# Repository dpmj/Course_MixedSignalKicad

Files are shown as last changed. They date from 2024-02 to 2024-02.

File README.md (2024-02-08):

# Mixed-Signal Hardware Design with KiCad

My complete KiCAD project and report.

All my content is licensed under CERN-OHL-S (CERN Open Hardware Licence Version 2 - Strongly Reciprocal). 

Third-party desing elements included in this repository are subject to the copyright of their respective owners.

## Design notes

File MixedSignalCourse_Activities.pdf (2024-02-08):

# Submission of course activities

### Mixed-Signal Hardware Design with KiCad

# Prof. Philip Salmony – FEDEVEL Academy

### Juan Del Pino Mena

dpmj@protonmail.com

Telecommunications Engineer

MEng. Telecommunications & MEng. Electronic Systems student

at Universitat Politècnica de València (Spain)

### February 8, 2024

Mixed-Signal Hardware Design with KiCad | Submission of course activities | 1

# This document is licensed under the CC BY-NC-SA 4.0 (Attribution-NonCommercial-ShareAlike 4.0 International)

The licensor cannot revoke these freedoms as long as you follow the license terms.

- Share – copy and redistribute the material in any medium or format
- Adapt – remix, transform, and build upon the material

Under the following terms:

- Attribution – You must give appropriate credit , provide a link to the license, and in-

dicate if changes were made . You may do so in any reasonable manner, but not in any

way that suggests the licensor endorses you or your use.

- NonCommercial – You may not use the material for commercial purposes.
- ShareAlike – If you remix, transform, or build upon the material, you must distribute

your contributions under the same license as the original.

# https://creativecommons.org/licenses/by-nc-sa/4.0/

Juan Del Pino Mena | 1

Mixed-Signal Hardware Design with KiCad | Submission of course activities | 2

# Contents

Lesson 3 | Part Selection | 3
Lesson 4 | How To Read A Datasheet and Circuit Design Introduction | 7
Lesson 5 | Schematic Design - Power Supply | 8
Lesson 6 | Schematic Design - Microcontroller, USB, SWD, and ESD Protection | 10
Lesson 8 | Final Schematic Tips, Footprint Selection, and Footprint Creation | 11
Lesson 9 | Circuit Simulation with LTSpice | 12
Lesson 11 PCB - Design Rules and Set-Up | 13
Lesson 12 PCB - Layout | 15
Lesson 13 PCB - Routing | 17
Lesson 14 PCB - Finishing touches | 22
Lesson 15 Getting The Product Manufactured | 23
Conclusions | 24
References | | 25

Mixed-Signal Hardware Design with KiCad | Submission of course activities | 3

# Lesson 3 Part Selection

# 3.1 Part Selection For Your Own Design

Try to follow the part selection steps (‘basics’) outlined in this video to perform the part

# selection for your own, previous electronics project. Have your part selections changed from what you previously chose? Did you require additional components?

Last year, for my bachelor’s thesis, I developed a portable device to capture and process

signals from two piezoelectric sensors and display the result on an LCD screen. It was my

first ‘serious’ PCB design. Due to my lack of experience and the limited stock in the lab I was

working in, I chose some components that I would not use now:

- The microcontroller was an Espressif ESP32-WROOM-32D, not the latest, but a very

popular µC in the DIY world, and it had the processing power and wireless capabili-

ties needed for the project. However, it’s not very well maintained and documented

(especially on the software side) and is not recommended for new designs (NRND).

- As the ESP32-WROOM-32D has no USB peripherals, a USB-to-UART converter was

needed. Again, due to various constraints, I ended up using a CH340C, which proved to

be very problematic. The USB port was a mini-USB, which is robust but discontinued.

- To save costs, the idea was to use the two ADC peripherals integrated in the ESP32-

WROOM-32D to acquire from both sensors simultaneously. However, in order to sample

at the required speed (about 200 kSps) it was essential to use DMA, but only one of the

peripherals was capable of using it, so the sampling rate had to be reduced. I also found

the acquisition period to be inconsistent.

- The device was powered by a Li-Po battery, and the charging circuitry was based on a

TP4056. Although simple, it’s a linear charger –so very inefficient– and had no power

path control.

Today, I think an adequate replacement would be the ESP32-S3-WROOM-1 for both the

ESP32-WROOM-32D and CH340C. If I ever needed a USB-to-UART converter, I would choose a

Silicon Labs CP2102N or similar. As for the ADCs, a more reliable alternative is the ADS78XX

series from Texas Instruments. The battery charger could be replaced by a switched mode

charger such as the BQ25629 from TI. And the USB port should be updated to a Type-C.

# 3.2 Distributor Part Search

Go to other electronics distributor websites (DigiKey, Farnell, ...) and try out their part

# search using the example from the video. How do the part searches compare? Which one do you prefer?

They are very similar. For electronic components, I personally prefer Mouser and DigiKey

to shops with a wider product range such as Farnell and RS Components because the search

filters are more precise. However, for specialised products such as microcontrollers, DC/DC

converters, sensors or ADCs, I prefer to select them directly from the manufacturer’s website

(STM, Analog, Microchip, TI...) and then search for stock and prices in online shops.

Mixed-Signal Hardware Design with KiCad | Submission of course activities | 4

# 3.3 Microcontroller Choice

# What microcontroller alternatives would you choose for this design? Are there any pinto-pin compatible microcontrollers that could be used as a replacement?

In Mouser, setting the filter to: Manufacturer = STM, Data bus width = 32 bits, Clock

Frequency = 48 MHz onwards, RAM = at least 20 kB, ROM = greater or equal than 128 kB

and Power supply = from 2.4 to 3.6 V. Leaving the package and number of pins unchosen and

sorting by price, the first microcontroller that appears in stock is the STM32F030CCT6. How-

ever, this µC lacks USB. Looking for similar chips on the manufacturer’s website but with USB

support, reveals the STM32F302C series, which are optimized for mixed-signal applications

and could even replace the ADCs.

A pin-to-pin compatible, drop-in replacement for the STM32F103CBT6 would be any of

the F1 or F3 series [1] with the same LQFP-48 package, like the STM32F302CBT6. The ability

to reconfigure the STM32 pins helps to find alternatives in the same manufacturer. Also, there

are clones of the popular STM32F103, e.g. the AIR32F103.

# 3.4 Data Converters

# What alternative data converters (ADCs and DACs) would you choose that are suitable for this application?

ADC The basic requirements are: single-channel (or more if price is not affected), single-

ended or differential, 12 bits, and at least 40 kSps, with SPI interface and support for 3.3

V. Some ≤ 2 e options gathered from Mouser:

## - Microchip MCP33141D / MCP33151D

## - OnSemi NCD98010 / NCD98011

- Texas Instruments ADS7826 / ADS7827 / ADS7829

DAC The requirements are identical to those of the ADC. Some inexpensive options are listed

below:

## - Analog Devices AD5601 / AD5611 / AD5621

## - Microchip MCP48FVB2X / MCP48CXB2X

- Texas Instruments DAC7512

# 3.5 Power Supplies

# If we use a linear, LDO regulator with a dropout voltage of +1V1 for all +3V3 rails in our design, what power loss would we suffer?

To calculate the dissipated power PD in a LDO, it is necessary to consider the dropout

voltage VDO and the current passing through it I. In our case, VDO = 1.1 V, but the current is

undefined. Assuming I = 0.1 A:

PD = VDO · I = 1.1 V · 0.1 A = 0.11W | (1)

Mixed-Signal Hardware Design with KiCad | Submission of course activities | 5

# 3.6 Analogue Circuitry

Compare the Johnson noise of the three following resistors: 100 Ohms, 1k, and 10k.

# What is the combined Johnson noise of two resistors in parallel, and two resistors in series?

Johnson noise, also known as thermal noise, arises due to the thermal agitation of charge

carriers in a resistive medium. It is characterized by its root mean square (RMS) voltage:

Vrms =

p
4 · kB · T · R · B | (2)
- kB is Boltzmann’s constant (≈ 1.38 × 10⁻²³ J/K).
- T is the temperature in Kelvin.
- R is the resistance in Ohms.
- B is the bandwidth in Hertzs.

Assuming a room temperature of T = 25 ◦C ≡ 298 K and a normalized bandwidth (B = 1 Hz),
the noise RMS voltage is 1.28 nV for 100 Ω, 4.06 nV for 1 kΩ, and 12.83 nV for 10 kΩ.

When combining two resistors, the noise will depend on their total resistance:

# Series RS = R1 + R2, so that Vrms,S =

p
4 · kB · T · (R1 + R2) · B. The sum of two resis-

tances greater than zero will always be greater than either part, and since the noise is

directly dependent on the resistance, it will also be greater.

# Parallel RP = R1||R2 =

R1·R2
R1+R2

, and so, Vrms,P =

q

# 4 · kB · T ·

R1·R2
R1+R2
- B. As we know, the

value resulting from the parallel of two resistors (non-zero and non-infinite) is less than

the value of the resistors themselves, so the noise will be lower.

# 3.7 Surrounding Circuitry

# Look up the differences between various ceramic capacitor types (X5R, Y5V, C0G, and so on). What are each’s benefits and drawbacks?

There are different classes of capacitor dielectrics [2]:

Class 1 Temperature compensating capacitors. They have a predictable temperature coeffi-

cient and do not tend to suffer with aging.

Class 2 General purpose ceramic capacitors. They offer high capacitance values in a small

size, but can be severely affected by temperature, voltage (both AC and DC), frequency

and aging.

In a MLCC capacitor, the first character of the code indicates the lowest temperature

that the capacitor can handle, the second character the maximum temperature, and the third

character the maximum amount of capacitance change over the part’s temperature range. A

qualitative comparison between several common types of capacitors is shown below:

X5R Relatively high capacitance per unit volume and are cost-effective. Suitable for applica-

tions where moderate capacitance are needed. However, X5R capacitors have a signifi-

cant capacitance change with temperature and voltage.

Mixed-Signal Hardware Design with KiCad | Submission of course activities | 6

Y5V High capacitance. Commonly used for decoupling, where their capacitance shift with

temperature and voltage are not critical. Their temperature operation range is reduced.

Z5U Similar to Y5V, but with narrowed operating temperature range.

X7R Good balance between temperature stability and capacitance values. Still not suitable

for high-precision applications.

C0G Also called NP0 (Class 1). Very low capacitance drift over temperature variations and

voltage biases. Low losses and high Q factors, suitable for precision applications. How-

ever, they tend to have lower capacitance values compared to class 2 capacitors. They

can also be more expensive.

Mixed-Signal Hardware Design with KiCad | Submission of course activities | 7

# Lesson 4 How To Read A Datasheet and Circuit Design Introduction

# Open the datasheet for the DAC IC used in this design. Is the datasheet arranged in a similar way? What are the key sections?

The datasheet of the DACxx6x series [3] is organised identically to the TLV62569 DC/DC

converter one. This is partly because all IC datasheets follow a similar structure, and mainly

because they are from the same manufacturer, Texas Instruments, which has very standardised

documents. The key sections are:

1. Features
2. Applications
3. Description
4. Revision history
5. Device comparison table
6. Pin configuration and functions
7. Specifications
8. Detailed description
9. Application and implementation
10. Power supply recommendations
11. Layout
12. Device and documentation support
13. Mechanical, packaging and orderable information

Mixed-Signal Hardware Design with KiCad | Submission of course activities | 8

# Lesson 5 Schematic Design - Power Supply

# 5.1 RLC Filters

# Using the online RLC filter tool, design an RLC low-pass filter that has a cut-off frequency of 100 kHz and damping ratio of 1.25. Inspect the frequency response, and note the inductor and resistor values. What capacitor size did you choose?

The data from avobe is entered in the RLC Low-pass Filter Design Tool hosted in Okawa

Electric Design website [4]: cutoff frequency 100 kHz and damping ratio 1.25. The capacitor

value is chosen as C = 100 nH. Forcing the value of the coil and the resistor to be from

commercial series, R = 39 Ω and L = 22 uH are obtained, which are adequate values. The

frequency response obtained is shown in Figure 1. Due to the constraint to stick to commercial

values, the cut-off frequency has slightly shifted to 107.3 kHz.

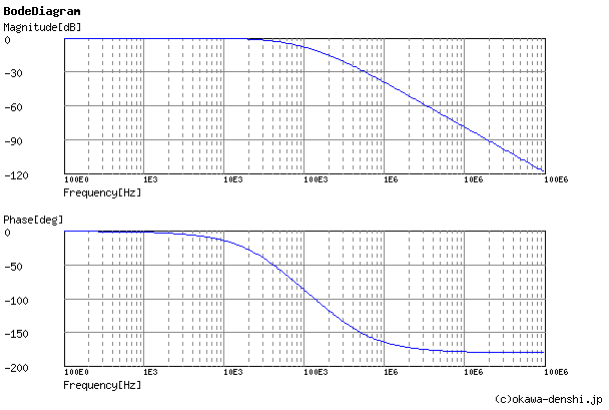
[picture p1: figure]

Figure 1 – Frequency response of the 100 kHz RLC filter designed in Okawa Electric Design website
[4].

# 5.2 RC Filters

# Cascade a high-pass RC filter with a low-pass RC filter, and set R=1k for both and C=1nF for both. What type of filter is the combined structure? What is the input impedance vs frequency?

Instead of using the online tool, it has been decided to use LTSpice in order to have more

control over the information obtained from the circuit.

The filter resulting from the cascade of the two proposed high-pass and low-pass filters

is a band-pass (see Figure 3). Due to the overlap of their cut-off frequencies, the passband

attenuates the signal considerably (6 dB). The figure also depicts the input impedance as a

function of frequency, which corresponds almost to that of the first stage: the high pass.

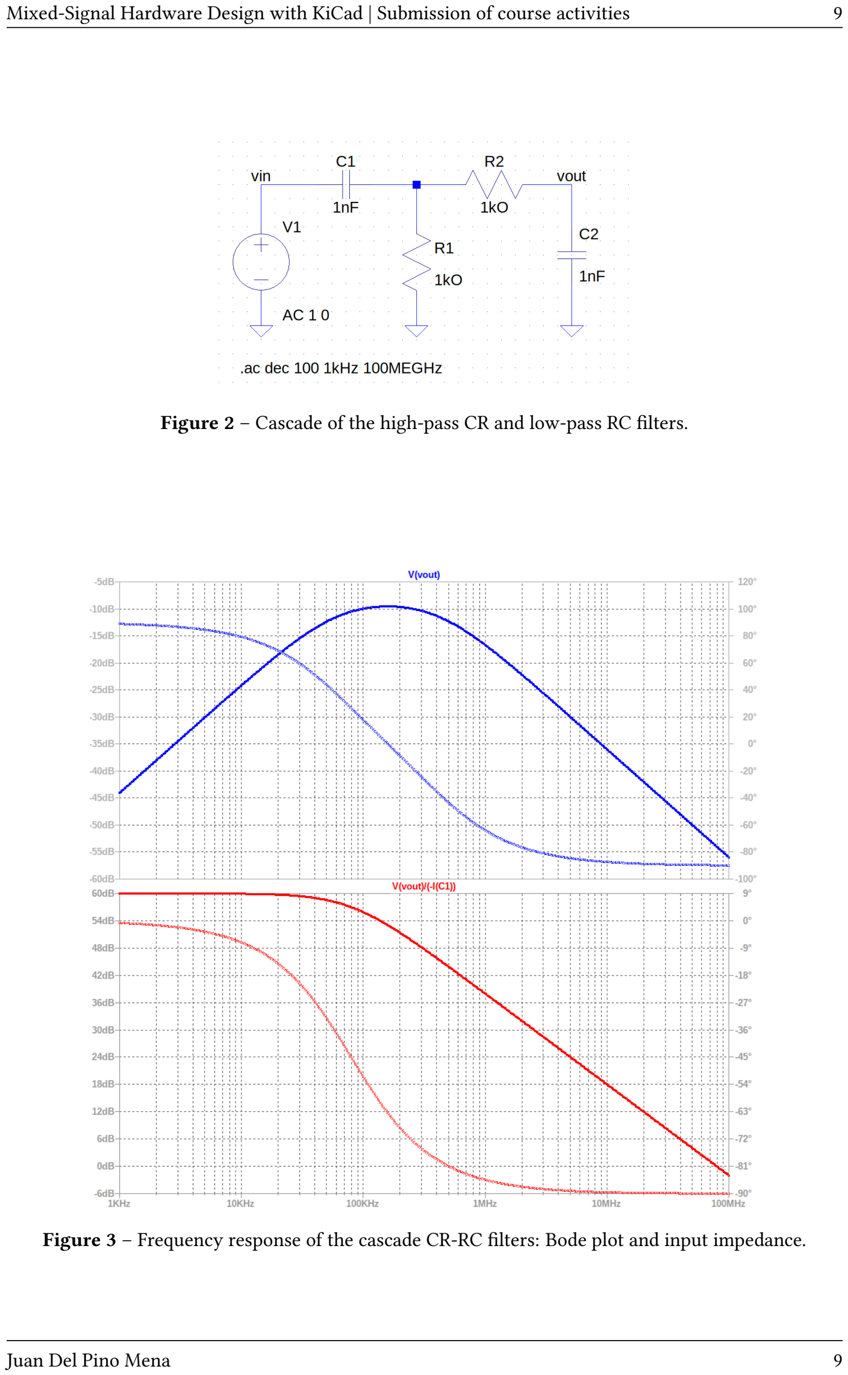
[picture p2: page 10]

Mixed-Signal Hardware Design with KiCad | Submission of course activities | 9

Figure 2 – Cascade of the high-pass CR and low-pass RC filters.

Figure 3 – Frequency response of the cascade CR-RC filters: Bode plot and input impedance.

Mixed-Signal Hardware Design with KiCad | Submission of course activities | 10

Lesson 6 Schematic Design - Microcontroller, USB, SWD,

# and ESD Protection

# Try to select a different STM32 microcontroller, download STM32CubeIDE, and do a

rough pin-out planning given the constraints of this project.

In subsection 3.3 we already discussed the STM32F302CBT6 as a suitable replacement for

the STM32F103CBT6, since it comes in the same LQFP-48 package and has similar characteris-

tics. After installing the STM32CubeIDE and creating a new project based on the STM32F302CBT6

microcontroller, the pin allocation takes place. See Figure 4 for the result, which is pin-to-pin

compatible with the pinout assignment performed in lesson 6.

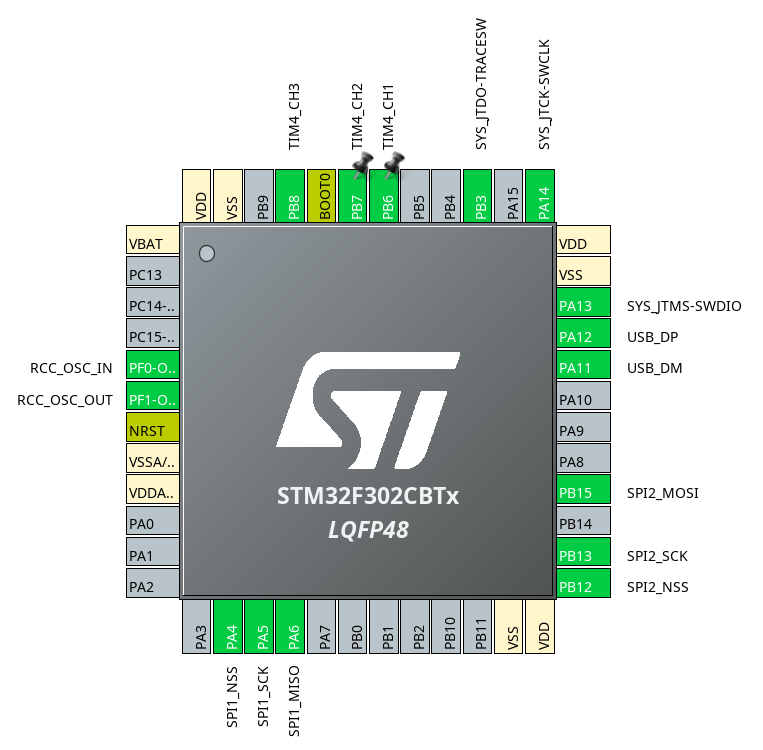
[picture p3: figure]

Figure 4 – STM32F302CBT6 rough pin planning.

Mixed-Signal Hardware Design with KiCad | Submission of course activities | 11

# Lesson 8 Final Schematic Tips, Footprint Selection, and Footprint Creation

# Have a go at trying to make your own footprint for a different part (e.g. the buck con-

verter IC) in KiCad using the datasheet as a guide.

Using the dimensions for the SOT-23-6 package in the TLV62569 DC/DC converter datasheet

[5], KiCad’s footprint wizard for SOIC packages, and the 3D model from Kirk Jess on 3DCon-

tentCentral [6], the footprint of the component has been synthesised, as shown in Figure 5.

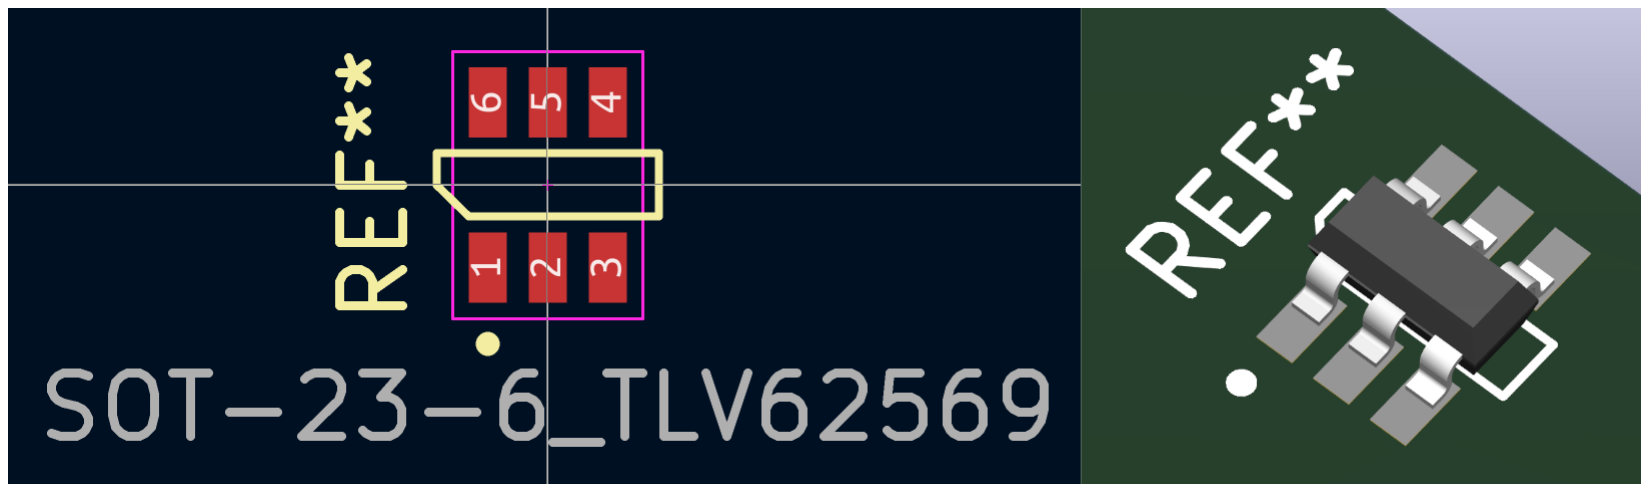
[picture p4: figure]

Figure 5 – 2D and 3D view of the TLV62569 footprint.

Mixed-Signal Hardware Design with KiCad | Submission of course activities | 12

# Lesson 9 Circuit Simulation with LTSpice

# Download and install LTSpice, then try and perform a frequency response analysis of

the 3rd order Butterworth anti-aliasing filter.

The simulated circuit comprises from the decoupling capacitor / high-pass filter at the

input of the follower, up to the balanced output (Figure 6). The resulting frequency response

is plotted in Figure 7. We can first observe the cutoff frequency of the high pass filter (which

differs from the schematic, since it is 0.723 Hz and not 1.4 Hz). The passband extends up to its

cut-off frequency of approximately 24 kHz. At 20 kHz there is an attenuation of about 1 dB.

This filter is suitable for audio applications.

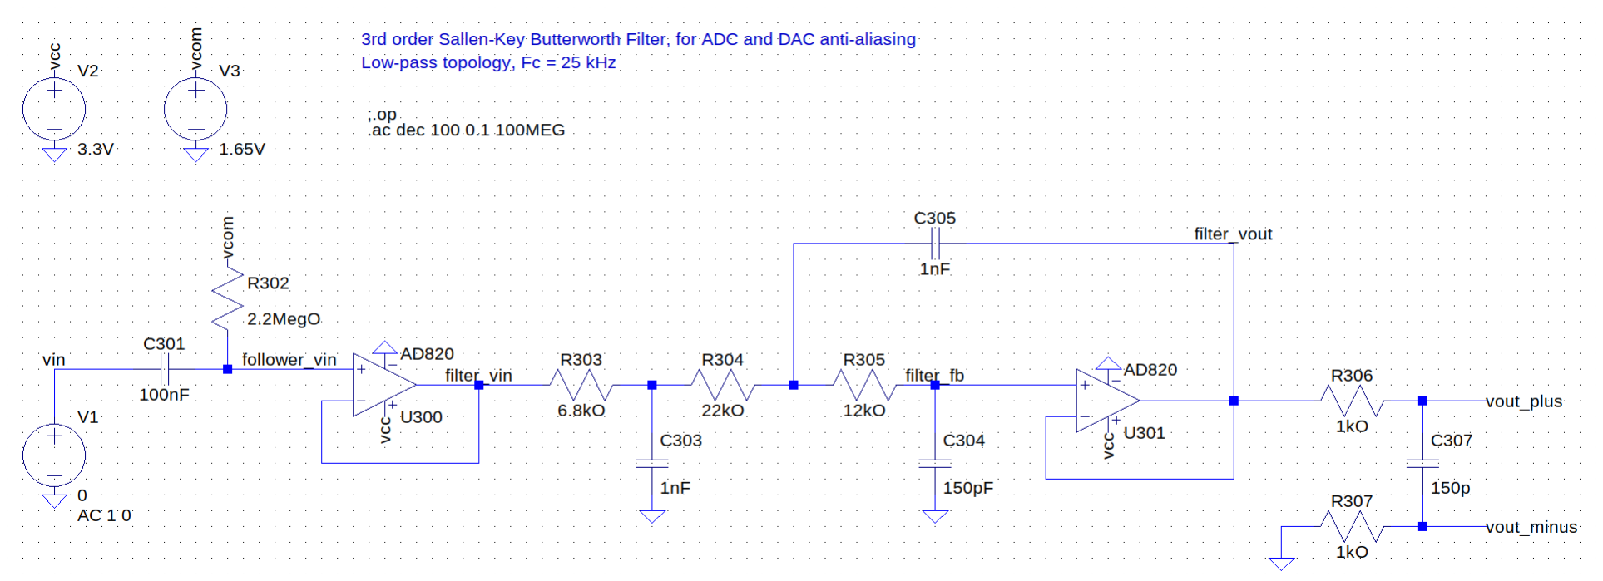
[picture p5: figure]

Figure 6 – Sallen-Key third-order butterworth filter circuit in LTSpice.

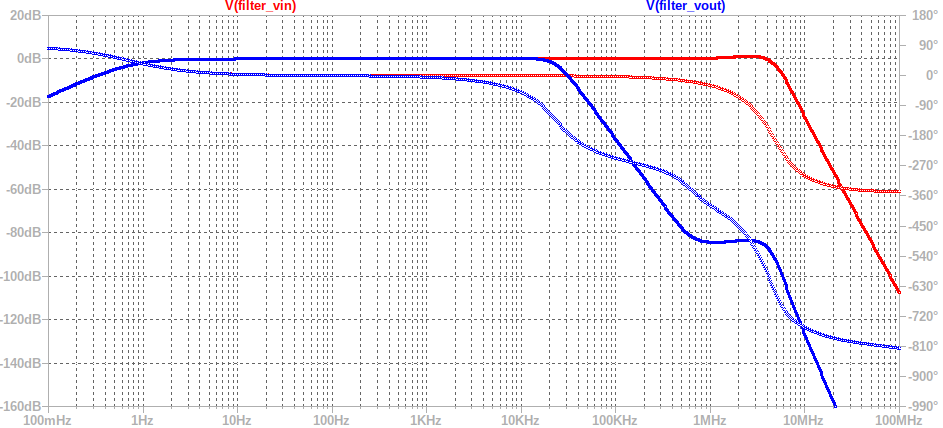
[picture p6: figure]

Figure 7 – Sallen-Key third-order butterworth filter frequency response in LTSpice.

Mixed-Signal Hardware Design with KiCad | Submission of course activities | 13

# Lesson 11 PCB - Design Rules and Set-Up

# Using your own preferred PCB manufacturer’s website, try and fill in all of the required

design rules, as shown in the video, in KiCad.

I have decided to use EuroCircuits as the PCB manufacturer, being one that I have not

used previously. Based on their documentation [7], [8], the 4-layer stackup from the Defined

Impedance Pool has been chosen, and a pattern class 6 and drill class C PCB has been selected.

The stackup and design rules have been specified in the KiCAD configuration as shown in the

screenshots in Figure 8 and Figure 9. The board finish is ENIG. With the chosen stackup, a

90 Ω differential pair at the USB high-speed frequency has the dimensions shown in Figure 10.

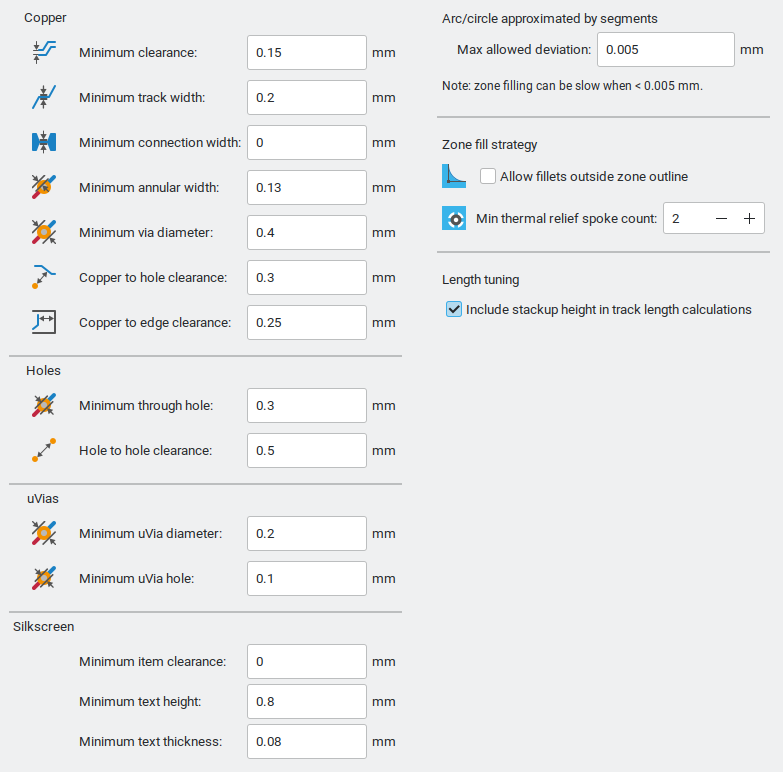
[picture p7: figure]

Figure 8 – KiCAD board setup - Constraints

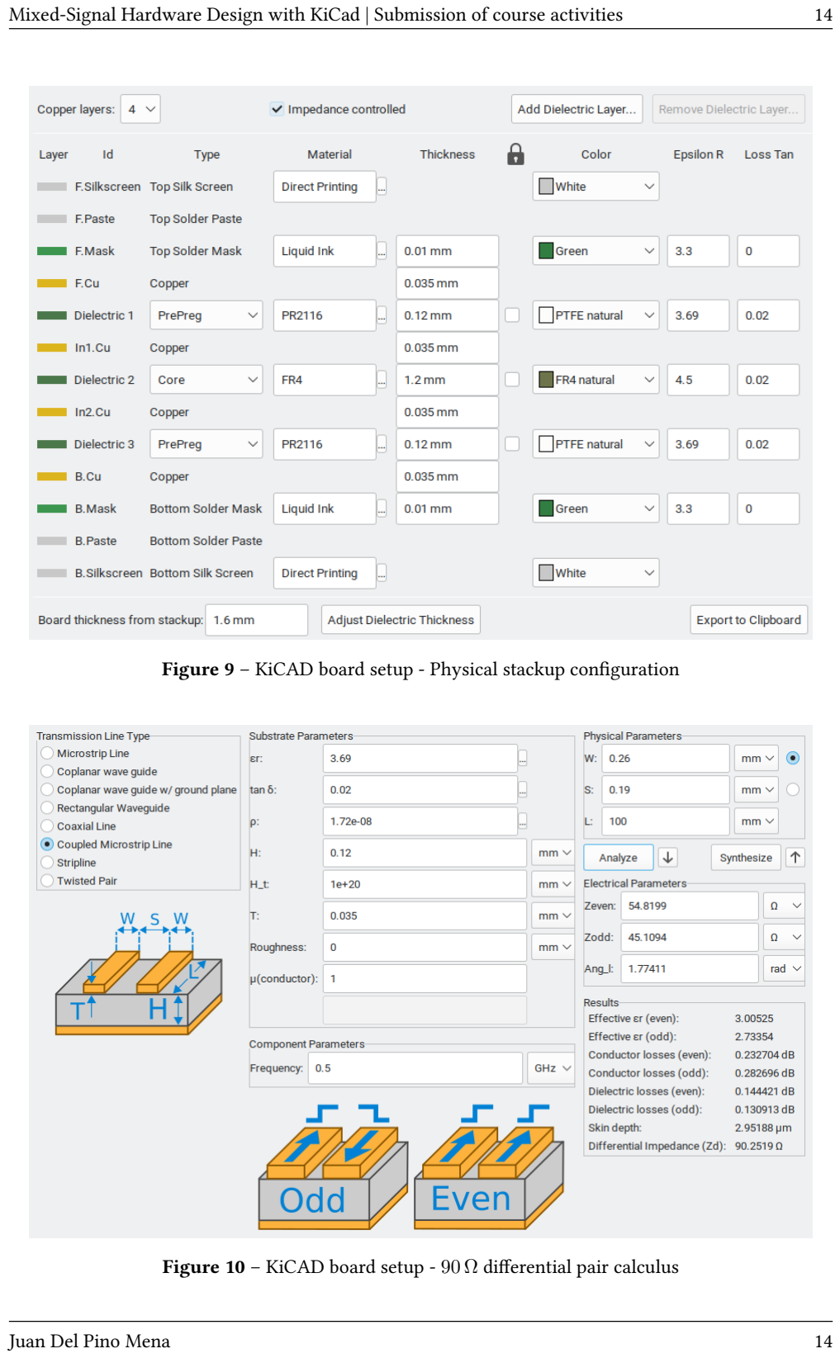
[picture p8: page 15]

Mixed-Signal Hardware Design with KiCad | Submission of course activities | 14

Figure 9 – KiCAD board setup - Physical stackup configuration

Figure 10 – KiCAD board setup - 90 Ω differential pair calculus

Mixed-Signal Hardware Design with KiCad | Submission of course activities | 15

# Lesson 12 PCB - Layout

# I would strongly encourage you to start from the finished schematic (project files in-

cluded in ’Lesson 1’), and follow along with the layout process - or even try to improve on the layout shown in the video. This step is needed to be eligible for a course certificate.

The missing 3D models from the BNC connectors, USB Type-C, ADC, DAC, buck con-

verter inductor, and common-mode choke have been added. Some have been obtained from

the built-in KiCAD library at $KICAD7_3DMODEL_DIR/ whereas others are in

# $KIPRJMOD/Juan_Footprints_Lib/3D/

Rather than following the video step by step and doing it exactly the same, I have decided

to follow the recommendations but varying the layout by constraining the design to a PCB

that fits a Hammond Manufacturing 1457C802EBK enclosure [9]. Clearance zones have been

defined to prevent components from colliding with the housing and its rails.

The early layout is shown in Figure 11. A 3D view of the board is shown in Figure 12.

The layout is divided into zones according to the schematic sheets, with enough space between

them for easy routing.

Note: As the 1457C802EBK case is EMC/EMI shielded, an extra earth net has been

added to the design to connect the mounting holes and the shield of the USB connector. Un-

fortunately, the BNC connectors can’t benefit from this earth, as the metal structure is directly

connected to GND.

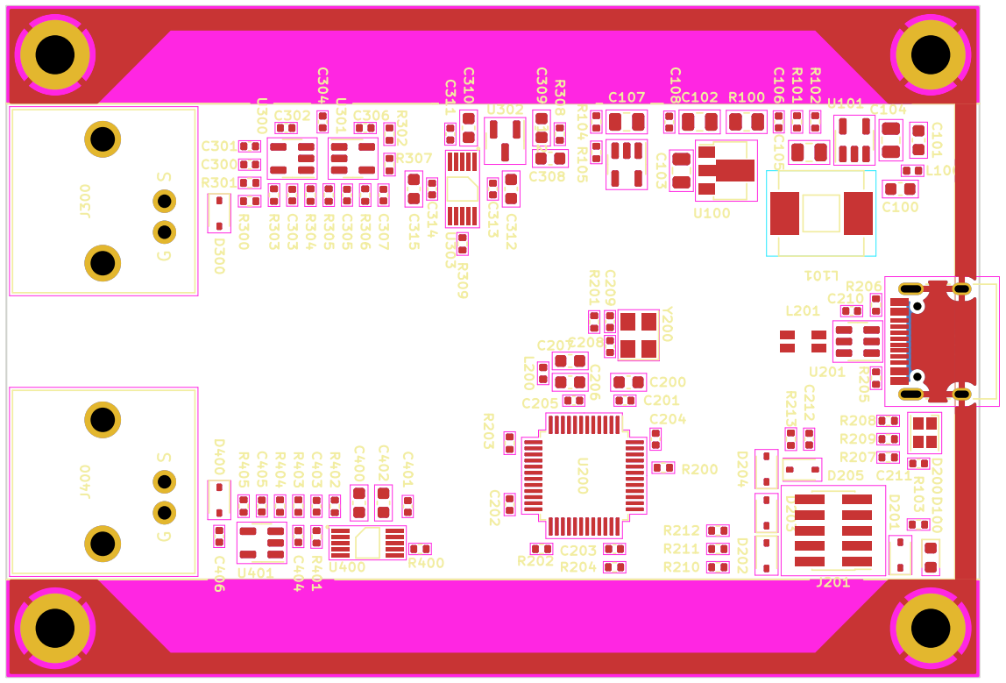
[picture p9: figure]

Figure 11 – Preliminary layout of the board – 2D view

Mixed-Signal Hardware Design with KiCad | Submission of course activities | 16

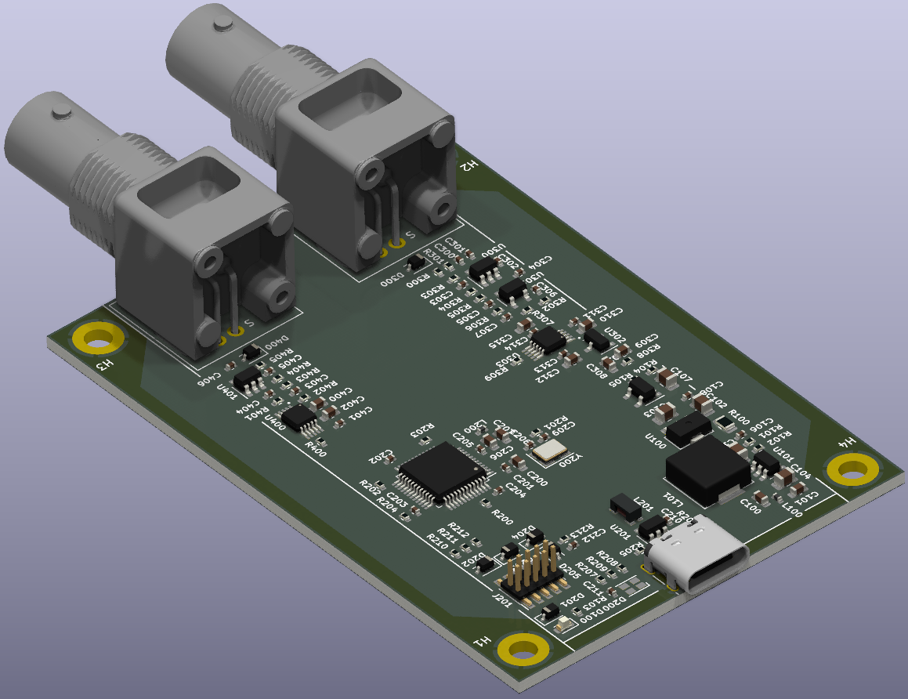
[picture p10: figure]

Figure 12 – Preliminary layout of the board – 3D view

Mixed-Signal Hardware Design with KiCad | Submission of course activities | 17

# Lesson 13 PCB - Routing

# You should now try to route out the complete PCB by yourself, following the guidelines

in this video. This step is needed to be eligible for a course certificate.

The layout of the board has undergone minimal change from previous lesson. The top

layer accommodates the majority of signal traces and routing, while the bottom layer provides

additional signal bridges and power distribution. Polygon pours are widely used, to optimise

for lower voltage drops –even for lower current circuits– given that there is plenty of space.

To ensure signal integrity, return path vias are placed for all signals undergoing layer

changes. In addition, via stitching is performed on both the ground and earth planes. Earth

features exposed copper to make a connection to the metal housing.

The board has no Design Rule Check errors. Some footprints had to be updated to solve

warnings. Only a handful of non-critical warnings remain, due to the silkscreen of the USB

being cropped by the board outline.

In Figure 13 an updated 3D view of the board is shown. On the following pages are

several prints of the board layers.

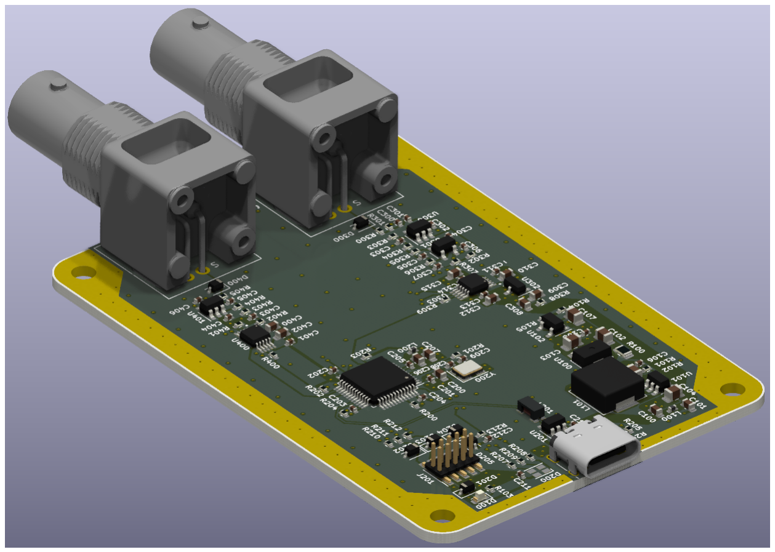
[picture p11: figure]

Figure 13 – 3D view of the board, finished layout and routing

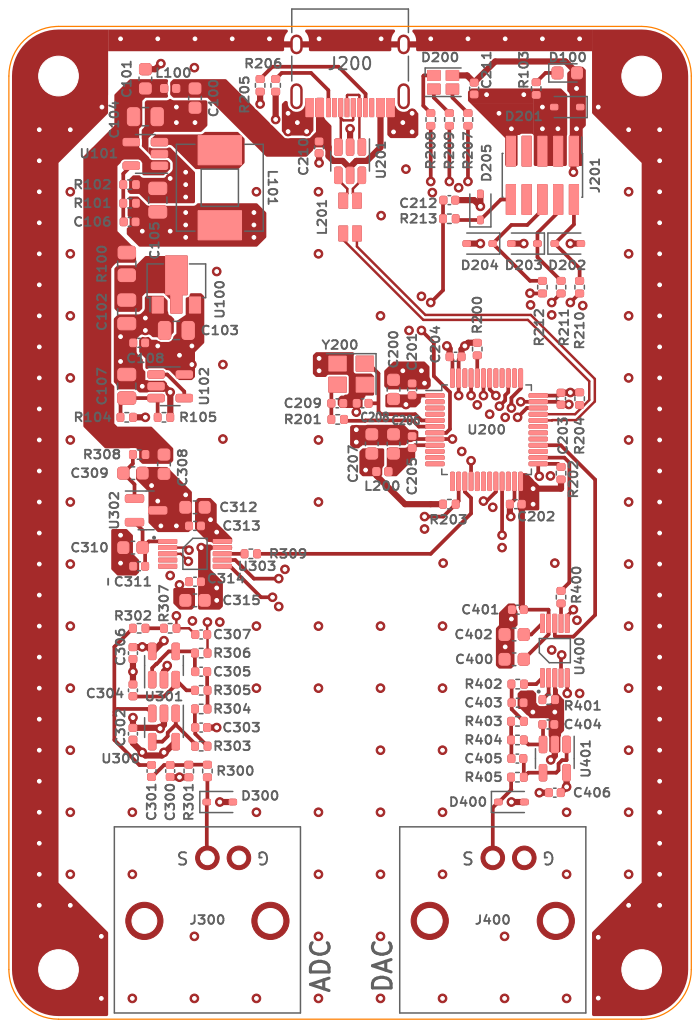
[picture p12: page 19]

File: Nemesis-MixSigPCB.kicad_pcb Sheet: Juan Del Pino Mena

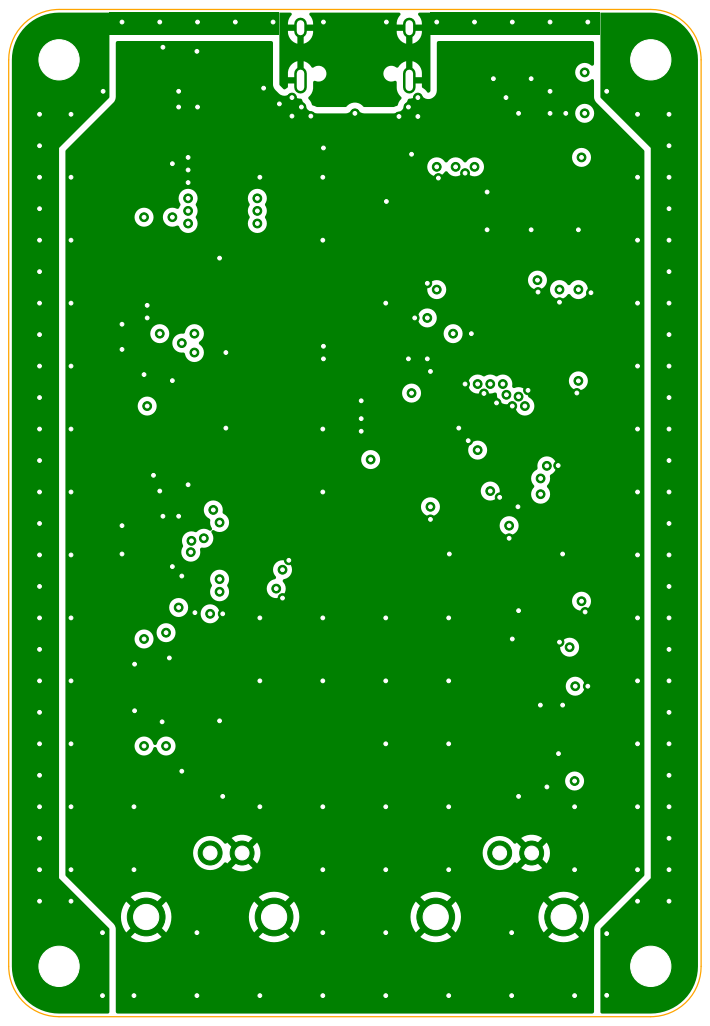
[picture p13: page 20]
D Date: 2023-09-22 KiCad; kicad; 7.0.10 Size: A4; Rev: 1; Id: 1/1 Title: Mixed-Signal; Hardware Design with KiCad - PCB; File: Nemesis-MixSigPCB.kicad_pcb Sheet: Juan; Del; Pino; Mena

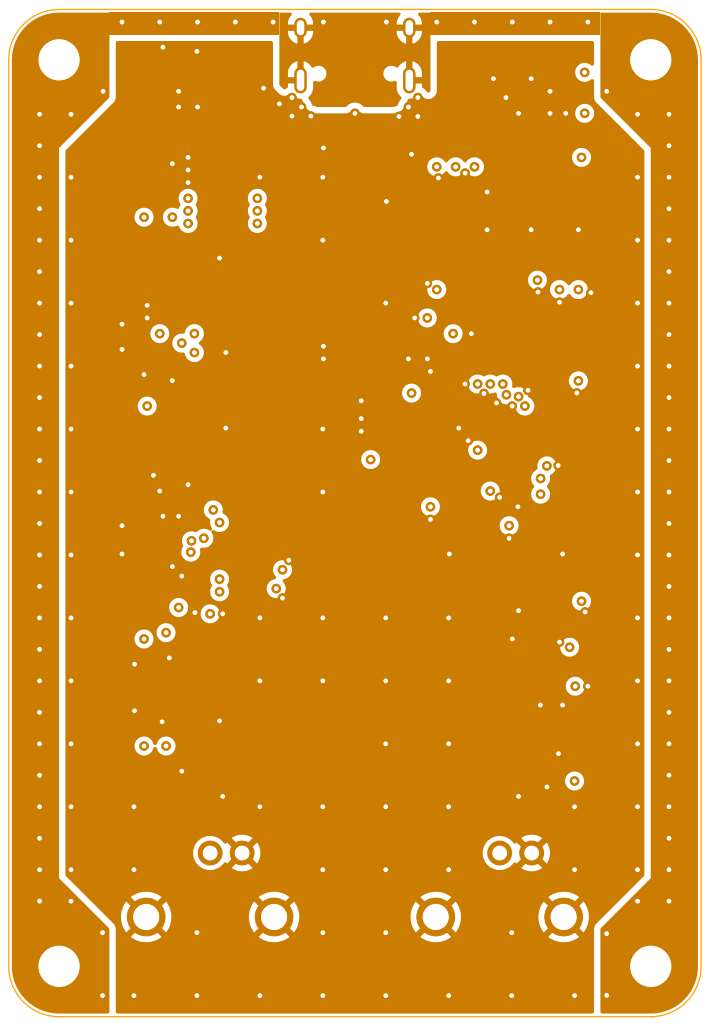
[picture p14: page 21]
D Date: 2023-09-22 KiCad; kicad; 7.0.10 Size: A4; Rev: 1; Id: 1/1 Title: Mixed-Signal; Hardware Design with KiCad - PCB; File: Nemesis-MixSigPCB.kicad_pcb Sheet: Juan; Del; Pino; Mena

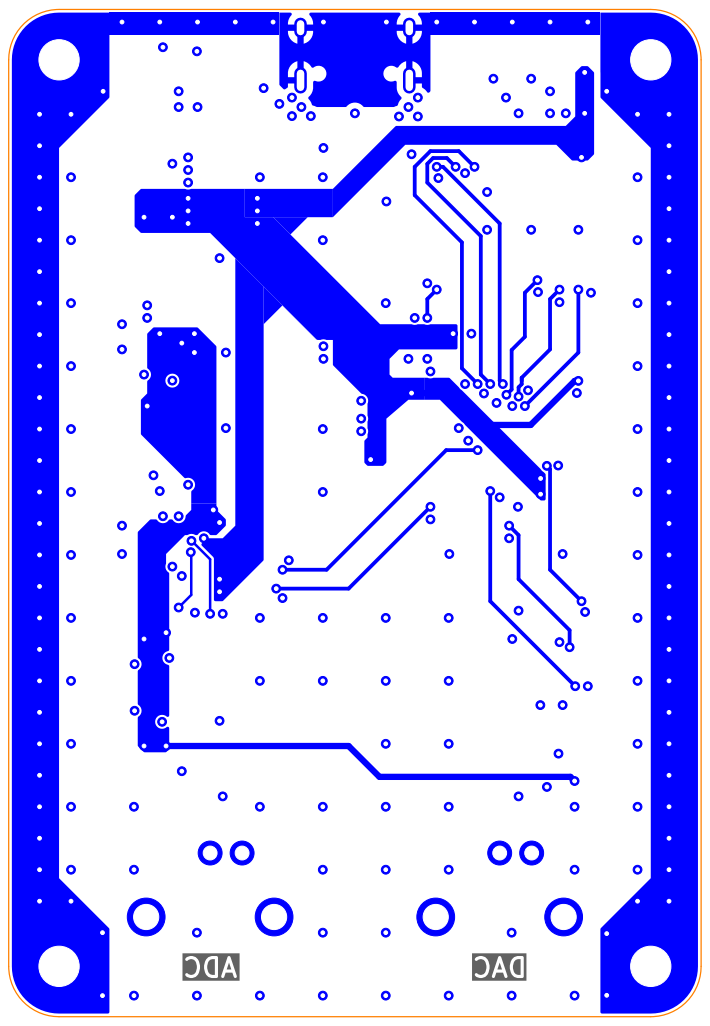
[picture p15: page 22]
D Date: 2023-09-22 KiCad; kicad; 7.0.10 Size: A4; Rev: 1; Id: 1/1 Title: Mixed-Signal; Hardware Design with KiCad - PCB; File: Nemesis-MixSigPCB.kicad_pcb Sheet: Juan; Del; Pino; Mena

Mixed-Signal Hardware Design with KiCad | Submission of course activities | 22

# Lesson 14 PCB - Finishing touches

# Try to add your own logo and silkscreen to your PCB design. How would you go about adding tooling holes for assembly?

Some decorative silkscreen has been added in the bottom layer.

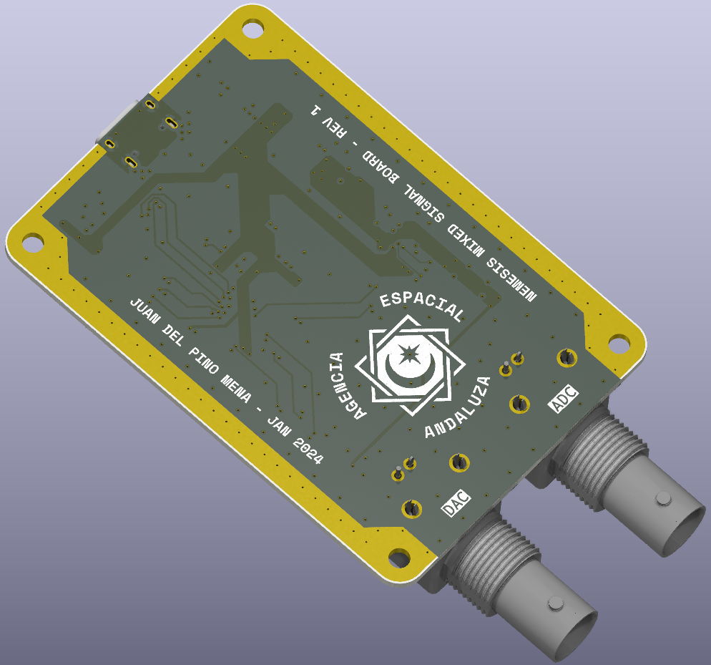
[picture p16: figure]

Figure 14 – 3D view of the board, bottom view.

Mixed-Signal Hardware Design with KiCad | Submission of course activities | 23

# Lesson 15 Getting The Product Manufactured

# Try to export Gerber and Drill files, as well as assembly files (footprint position and

BOM) for yourself in KiCad.

A manufacturer and part number has been provided for every component in the design.

Gerber and Drill files are exported to the Gerber/ folder inside the project. Gerber files have

been checked. Assembly files (placement and bill of materials) are placed in the Assembly/

folder.

JLCPCB automatically detects all features of the board when the gerbers are uploaded.

Selected specs are: 4 layers, controlled impedance (stackup JLC0416H-7628), green solder

mask, white silkscreen, FR-4 TG 155ºC, ENIG surface finish, 1 oz/ft² in external layers, 0.5

oz/ft² in internal layers, plugged vias, 0.3 mm minimum via hole, 0.2 mm tolerance in board

cutout, and assembly of 5 boards. The price is $ 37.39.

In Eurocircuits both the gerbers and the assembly files are correctly identified. For the

controlled impedance pool (which is the one actually this project is designed for), and selecting

similar specs to those selected in JLCPCB, the total price is e 220.70.

Mixed-Signal Hardware Design with KiCad | Submission of course activities | 24

# Conclusions

I found this course quite complete. The explanations were clear, sufficient and practical, high-

lighting the key aspects needed to develop intuition when designing boards. I already had

some experience, but I found all the details explained in the schematics, topology and compo-

nent selection very helpful.

Giving the students basic materials is a double-edged sword: on the one hand, it gives ev-

eryone a common starting point, abstracts some of the design process and speeds up progress

towards completion. But on the other hand, we lose part of the experience. I think I would

have done an extra lesson on how to create a new schematic sheet from scratch. It would also

have been nice to take advantage of the extensive and high quality symbol, footprint and 3D

libraries that come with KiCAD.

I found some problems with the resources provided, such as outdated PCB footprints

and schematic symbols, which were annoying. But on the positive side, these problems made

me look for solutions on my own, and I became more confident with KiCAD.

Also, this was my first project in KiCAD and I found it very fast, convenient and exten-

sible. In some ways I think it puts bloated software like Altium Designer to shame. Thank you

for introducing me to this wonderful piece of open source software!

Mixed-Signal Hardware Design with KiCad | Submission of course activities | 25

# References

[1] ST Microelectronics Inc., Migrating from STM32F1 Series to STM32F3 Series microcontrollers, Appli-

cation Note AN4228. DocID024110, Rev 6, Feb 2017. Available online: https://www.st.com/

# resource / en / application _ note / dm00024853 - migration - and - compatibility -

guidelines- for- stm32- microcontroller- applications- stmicroelectronics. pdf. (https://www.st.com/resource/en/application_note/dm00024853-migration-and-compatibility-guidelines-for-stm32-microcontroller-applications-stmicroelectronics.pdf)

[2] C. Kaiser, The Capacitor Handbook. Springer Netherlands, 2012, isbn: 9789401180900.
[3] T. I. Inc., DACxx6x series datasheet, Document number SLAS719E, August 2010, Revised June 2015.
Available online: https://www.ti.com/lit/gpn/DAC7563.
[4] O. E. Design, Engineering design utilities, Available online: http://sim.okawa-denshi.jp/

# en/. (http://sim.okawa-denshi.jp/en/)

[5] T. I. Inc., TLV62569 datasheet, Document number SLVSDG1C. December 2016, Revised October
2017. Available online: https://www.ti.com/lit/gpn/tlv62569.
[6] K. Jess, SOT-23-6 3D model, Available online: https://www.3dcontentcentral.es/downloadmodel.aspx?catalogid=171&id=93222. (https://www.3dcontentcentral.es/download-model.aspx?catalogid=171&id=93222)
[7] Eurocircuits, PCB configurator: Services, pool, technology, buildup, Available online: https://be.eurocircuits.com/shop/assembly/configurator.aspx. (https://be.eurocircuits.com/shop/assembly/configurator.aspx)
[8] Eurocircuits, PCB design guidelines: Classification, Available online: https://www.eurocircuits.com/pcb-design-guidelines/classification/. (https://www.eurocircuits.com/pcb-design-guidelines/classification/)
[9] Hammond Manufacturing Ltd., EMI/RFI shielded extruded aluminum enclosure, pn 1457c802ebk datasheet, Available online: https://www.hammfg.com/files/parts/pdf/1457C802EBK.

# pdf. (https://www.hammfg.com/files/parts/pdf/1457C802EBK.pdf)

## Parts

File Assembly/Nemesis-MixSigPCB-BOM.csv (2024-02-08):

Source: | /home/boi/Syncthing/Courses/2023-08 PhilsLab KiCad MixedSignal/MixSigCouse-KiCad-Files/Nemesis-MixSigPCB.kicad_sch
Date: | Sun 21 Jan 2024 09:14:26 PM CET
Tool: | Eeschema 7.0.10
Generator: | /usr/share/kicad/plugins/bom_csv_grouped_by_value_with_fp.py
Component Count: | 114
Ref | Qnty | Value | Cmp name | Footprint | Description | Vendor | DNP | Manufacturer | Manufacturer Part Number
C100, C101, C206, C207, C402 | 5 | 1u | C | Capacitor_SMD:C_0603_1608Metric | Unpolarized capacitor |  | KEMET | C0603C105K8RACAUTO7411
C102, C103, C104, C105, C107 | 5 | 22u | C | Capacitor_SMD:C_0805_2012Metric | Unpolarized capacitor |  | Samsung Electro-Mechanics | CL21A226KPCLRNC
C106 | 1 | DNP | C | Capacitor_SMD:C_0402_1005Metric | Unpolarized capacitor
C108, C201, C202, C203, C204, C210, C211, C212, C301, C302, C306, C311, C313, C314, C401, C406 | 16 | 100n | C | Capacitor_SMD:C_0402_1005Metric | Unpolarized capacitor |  | KEMET | C0402C104K8RACAUTO
C200, C308, C309, C310, C312, C315, C400 | 7 | 10u | C | Capacitor_SMD:C_0603_1608Metric | Unpolarized capacitor |  | Samsung Electro-Mechanics | CL10A106KQ8NNNL
C205 | 1 | 10n | C | Capacitor_SMD:C_0402_1005Metric | Unpolarized capacitor |  | KEMET | C0402C103K4RACAUTO
C208, C209 | 2 | 10p | C | Capacitor_SMD:C_0402_1005Metric | Unpolarized capacitor |  | Murata Electronics | GRT1555C1H100FA02D
C300, C304, C307, C404 | 4 | 150p | C | Capacitor_SMD:C_0402_1005Metric | Unpolarized capacitor |  | Walsin | 0402N151F100CT
C303, C305, C403, C405 | 4 | 1n | C | Capacitor_SMD:C_0402_1005Metric | Unpolarized capacitor |  | YAGEO | AC0402JRNPO9BN102
D100 | 1 | GREEN | LED | LED_SMD:LED_0603_1608Metric | Light emitting diode
D200 | 1 | LED_RGB_E6C1206RGBC3UDA | LED_RGB_E6C1206RGBC3UDA | LED_SMD:LED_Cree-PLCC4_2x2mm_CW |  |  | EKINGLUX | E6C1206RGBC3UDA
D201, D202, D203, D204, D205, D300, D400 | 7 | PESD3V3L1BA,115 | D_TVS | Diode_SMD:D_SOD-323 | Bidirectional transient-voltage-suppression diode |  | Nexperia | PESD3V3L1BA,115
H1, H2, H3, H4 | 4 | MountingHole_Pad | MountingHole_Pad | MountingHole:MountingHole_3.2mm_M3_ISO7380_Pad | Mounting Hole with connection
J200 | 1 | USB_C_Receptacle_USB2.0 | USB_C_Receptacle_USB2.0 | Juan_Footprints_Lib:USB_C_Receptacle_HRO_TYPE-C-31-M-12 | USB 2.0-only Type-C Receptacle connector |  | Korean Hroparts Elec | TYPE-C-31-M-12
J201 | 1 | 2x5 1.27mm | Conn_02x05_Odd_Even | Connector_PinHeader_1.27mm:PinHeader_2x05_P1.27mm_Vertical_SMD | Generic connector, double row, 02x05, odd/even pin numbering scheme (row 1 odd numbers, row 2 even numbers), script generated (kicad-library-utils/schlib/autogen/connector/) |  | Harwin | M50-3600542R
J300, J400 | 2 | 031-5640-1010 | Conn_Coaxial | PhilsLab_Footprints_KiCad6:AMPHENOL-BNC-031-5640-1010 | coaxial connector (BNC, SMA, SMB, SMC, Cinch/RCA, LEMO, ...) |  | Amphenol RF | 031-5640
L100, L200 | 2 | 10n | L | Inductor_SMD:L_0402_1005Metric | Inductor |  | ABRACON | AISC-0402HP-10NJ-T
L101 | 1 | 15u | L | PhilsLab_Footprints_KiCad6:MWSA0603S | Inductor |  | Shenzhen Sunlord Electronics | MWSA0603S-150MT
L201 | 1 | CMF3216F-900-2P-T | EMI_Filter_LL_1423 | PhilsLab_Footprints_KiCad6:CMC-1206 |  |  | HYHONGYEX | CMF3216F-900-2P-T
R100 | 1 | 10R | R | Resistor_SMD:R_0805_2012Metric | Resistor |  | Bourns | CHP0805AJW-100ELF
R101 | 1 | 100k | R | Resistor_SMD:R_0402_1005Metric | Resistor |  | Panasonic | ERJ-U02J104X
R102, R304, R403 | 3 | 22k | R | Resistor_SMD:R_0402_1005Metric | Resistor |  | Bourns | CR0402-JW-223GLF
R103, R104, R105, R207, R208, R209, R300, R306, R307 | 9 | 1k | R | Resistor_SMD:R_0402_1005Metric | Resistor |  | Bourns | CR0402-JW-102GLF
R200, R202, R203, R401 | 4 | 10k | R | Resistor_SMD:R_0402_1005Metric | Resistor |  | Panasonic | ERJ-PA2J103X
R201, R309, R400 | 3 | 0R | R | Resistor_SMD:R_0402_1005Metric | Resistor |  | Bourns | CR0402AJ/-000GAS
R204 | 1 | 1k5 | R | Resistor_SMD:R_0402_1005Metric | Resistor |  | Panasonic | ERJ-PA2J152X
R205, R206 | 2 | 5k1 | R | Resistor_SMD:R_0402_1005Metric | Resistor |  | Bourns | CR0402-JW-512GLF
R210, R211, R212, R213, R308, R405 | 6 | 49R9 | R | Resistor_SMD:R_0402_1005Metric | Resistor |  | Panasonic | ERJ2RKD49R9X
R301, R302 | 2 | 2M2 | R | Resistor_SMD:R_0402_1005Metric | Resistor |  | Panasonic | ERJ-U02J205X
R303, R402 | 2 | 6k8 | R | Resistor_SMD:R_0402_1005Metric | Resistor |  | Panasonic | ERJ-2GEJ682X
R305, R404 | 2 | 12k | R | Resistor_SMD:R_0402_1005Metric | Resistor |  | Bourns | CR0402-JW-123GLF
U100 | 1 | HT7533-1 | HT75xx-1-SOT89 | Package_TO_SOT_SMD:SOT-89-3 | 100mA Low Dropout Voltage Regulator, Fixed Output, SOT89 |  | Holtek | HT7533-1-SOT89
U101 | 1 | TLV62569DBV | TLV62569DBV | Package_TO_SOT_SMD:SOT-23-5 | High Efficiency Synchronous Buck Converter, Adjustable Output 0.6V-5.5V, 2A, SOT-23-5 |  | Texas Instruments | TLV62569DBVT
U102, U300, U301, U401 | 4 | MCP6001T-E/OT | MCP6001-OT | Package_TO_SOT_SMD:SOT-23-5 | 1MHz, Low-Power Op Amp, SOT-23-5 |  | Microchip Technology | MCP6001T-E/OT
U200 | 1 | STM32F103CBT6 | STM32F103CBTx | Package_QFP:LQFP-48_7x7mm_P0.5mm | ARM Cortex-M3 MCU, 128KB flash, 20KB RAM, 72MHz, 2-3.6V, 37 GPIO, LQFP-48 |  | STMicroelectronics | STM32F103CBT6
U201 | 1 | USBLC6-2SC6 | USBLC6-2SC6 | Package_TO_SOT_SMD:SOT-23-6 | Very low capacitance ESD protection diode, 2 data-line, SOT-23-6 |  | STMicroelectronics | USBLC6-2SC6
U302 | 1 | REF3033AIDBZT | REF3033 | Package_TO_SOT_SMD:SOT-23 | 3.3V 50-ppm/°C Max, 50-μA, CMOS Voltage Reference, SOT-23-3 |  | Texas Instruments | REF3033AIDBZT
U303 | 1 | ADC141S626CIMM_NOPB | ADC141S626CIMM_NOPB | PhilsLab_Footprints_KiCad6:VSSOP-10 |  |  | Texas Instruments | ADC141S626CIMM/NOPB
U400 | 1 | DAC7563SDGSR | DAC7563SDGSR | PhilsLab_Footprints_KiCad6:VSSOP-10 |  |  | Texas Instruments | DAC7563SDGSR
Y200 | 1 | 16MHz | Crystal_GND24 | Crystal:Crystal_SMD_3225-4Pin_3.2x2.5mm | Four pin crystal, GND on pins 2 and 4 |  | ECS | ECS-TXO-3225MV-160-TR

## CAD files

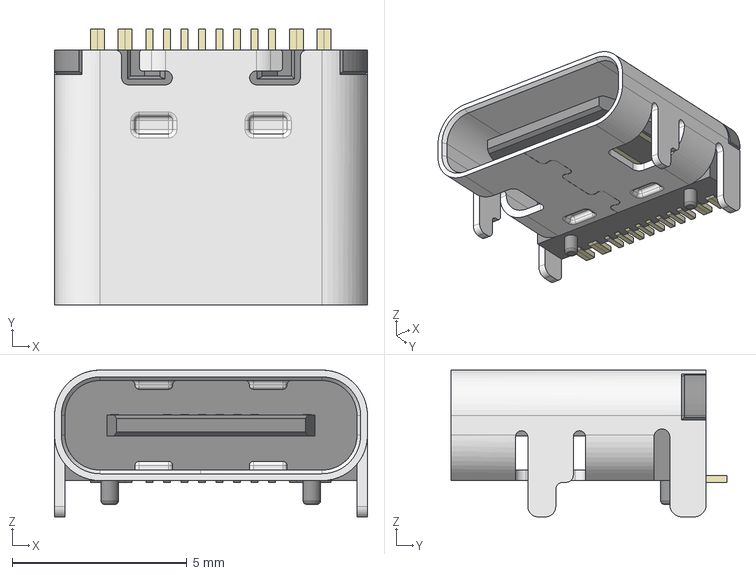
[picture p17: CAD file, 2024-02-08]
Juan_Footprints_Lib/3D/HRO_TYPE-C-31-M-12.step
8.95 x 7.90 x 4.20 mm

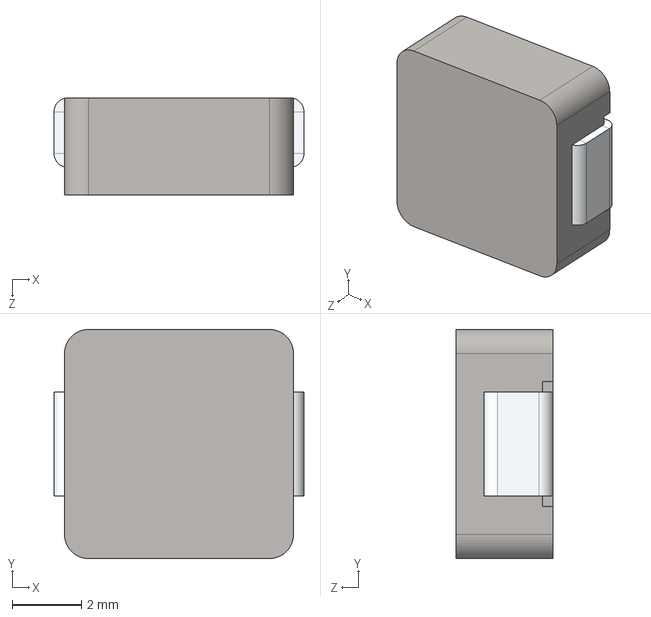
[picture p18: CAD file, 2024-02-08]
Juan_Footprints_Lib/3D/User Library-MWSA0603S.STEP
7.20 x 6.60 x 2.80 mm
MWSA0603S-HOUSE.STP
MWSA0603S-PIN.STP

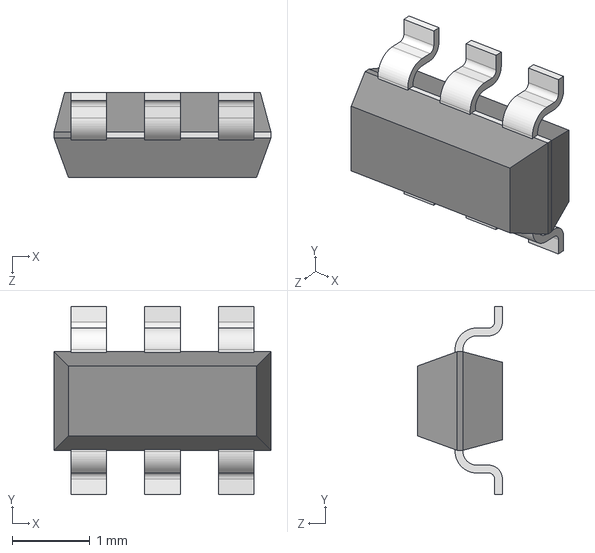
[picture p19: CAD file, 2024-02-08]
Juan_Footprints_Lib/3D/SOT-23-6.step
2.79 x 2.43 x 1.09 mm

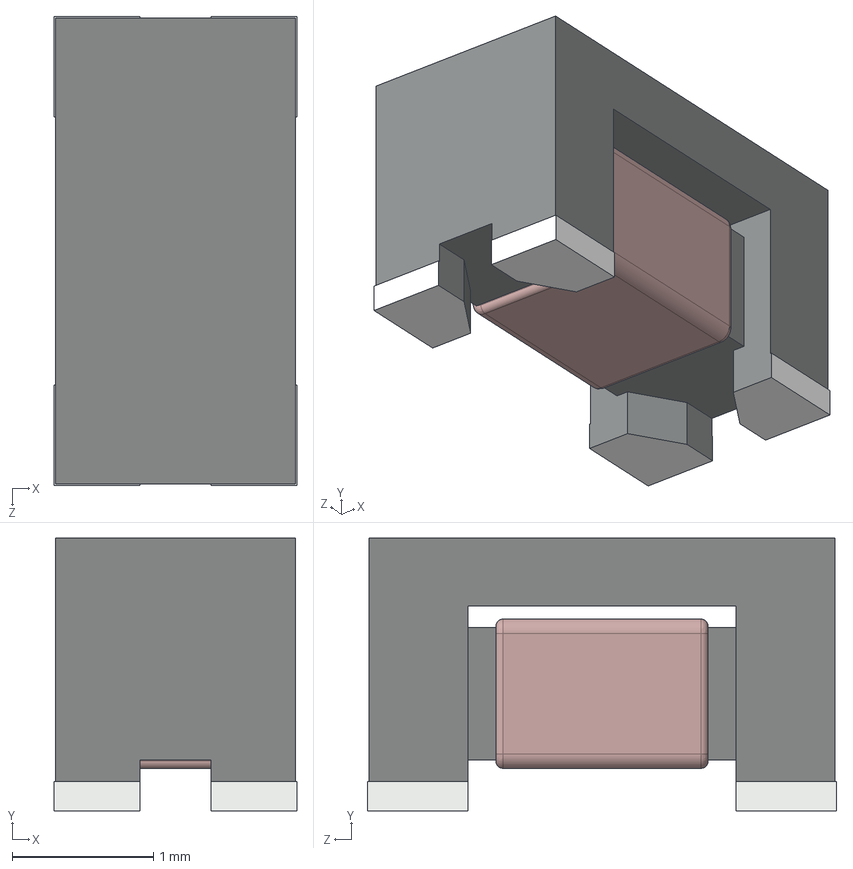
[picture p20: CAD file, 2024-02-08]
Juan_Footprints_Lib/3D/Coilcraft-1206USB.STEP
1.72 x 1.93 x 3.32 mm

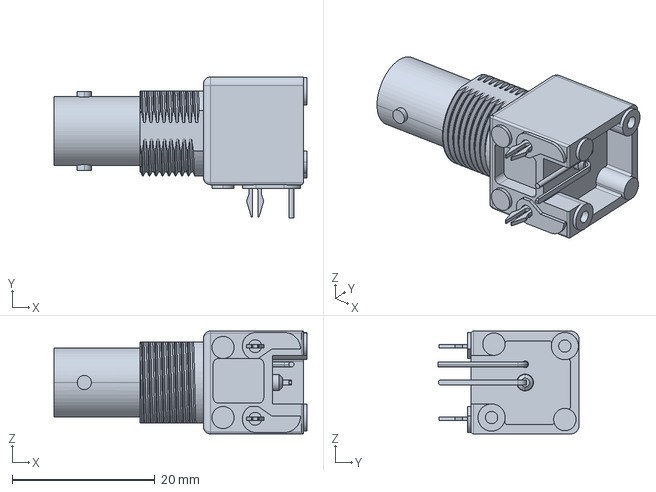
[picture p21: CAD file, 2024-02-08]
Juan_Footprints_Lib/3D/31-5640-1010.stp
35.4 x 19.8 x 14.4 mm

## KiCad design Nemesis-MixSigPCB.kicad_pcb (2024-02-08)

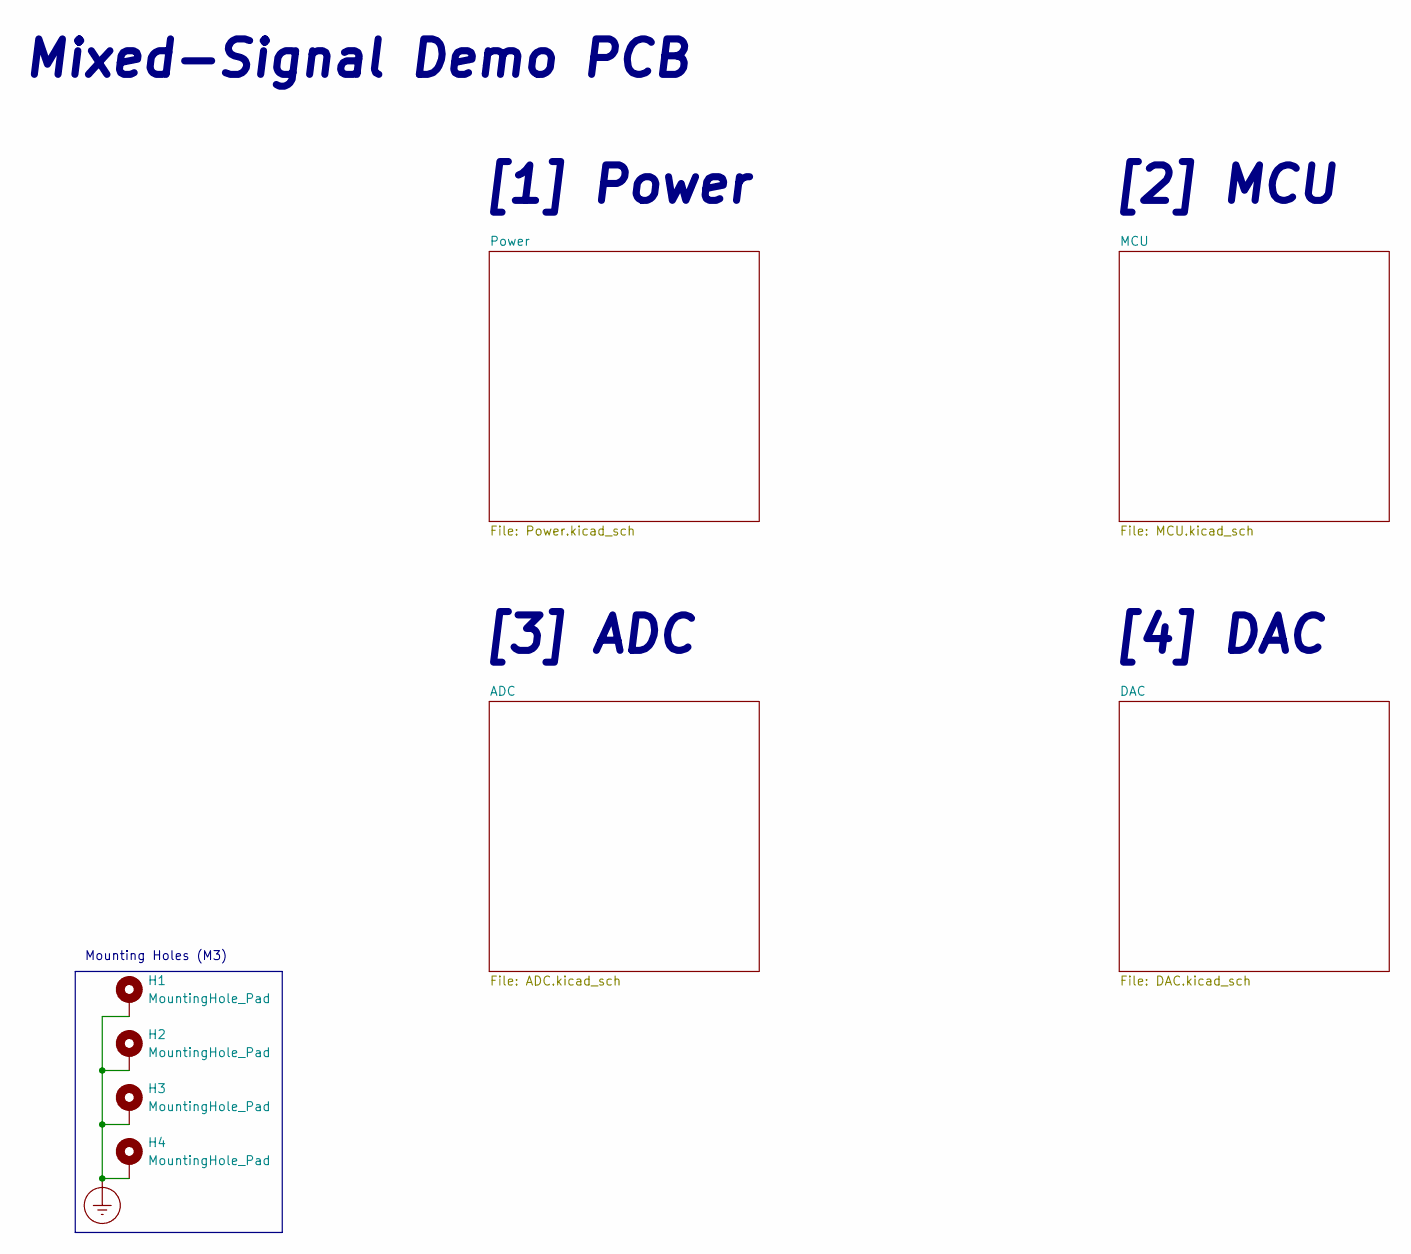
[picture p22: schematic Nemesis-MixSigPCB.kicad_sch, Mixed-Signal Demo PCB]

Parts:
H1, H2, H3, H4: MountingHole_Pad; MountingHole_3.2mm_M3_ISO7380_Pad

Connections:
Earth_Protective: H1.1, H2.1, H3.1, H4.1; also elsewhere on the board

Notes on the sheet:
[4] DAC
Mixed-Signal Demo PCB
[3] ADC
Mounting Holes (M3)
[2] MCU
[1] Power

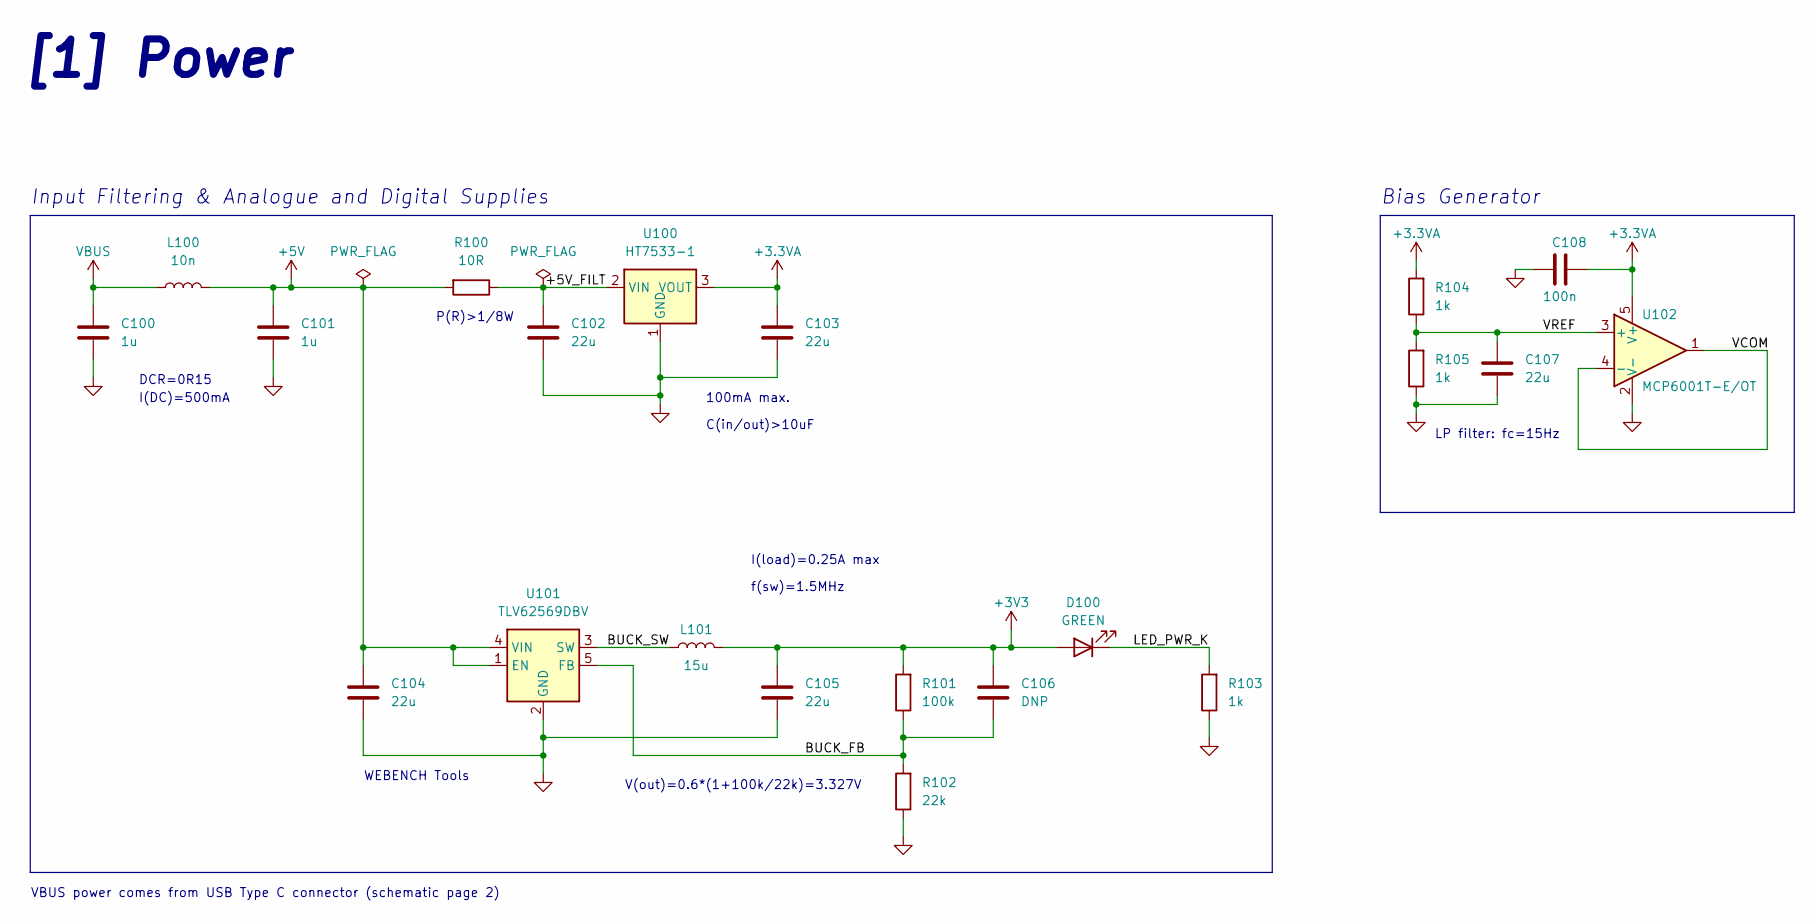
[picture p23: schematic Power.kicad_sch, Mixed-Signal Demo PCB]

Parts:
C100, C101: 1u; C_0603_1608Metric; Manufacturer Part Number C0603C105K8RACAUTO7411
C102, C103, C104, C105, C107: 22u; C_0805_2012Metric; Manufacturer Part Number CL21A226KPCLRNC
C106: DNP; C_0402_1005Metric
C108: 100n; C_0402_1005Metric; Manufacturer Part Number C0402C104K8RACAUTO
D100: GREEN; LED_0603_1608Metric
L100: 10n; L_0402_1005Metric; Manufacturer Part Number AISC-0402HP-10NJ-T
L101: 15u; MWSA0603S; Manufacturer Part Number MWSA0603S-150MT
R100: 10R; R_0805_2012Metric; Manufacturer Part Number CHP0805AJW-100ELF
R101: 100k; R_0402_1005Metric; Manufacturer Part Number ERJ-U02J104X
R102: 22k; R_0402_1005Metric; Manufacturer Part Number CR0402-JW-223GLF
R103, R104, R105: 1k; R_0402_1005Metric; Manufacturer Part Number CR0402-JW-102GLF
U100: HT7533-1; SOT-89-3; Manufacturer Part Number HT7533-1-SOT89
U101: TLV62569DBV; SOT-23-5; Manufacturer Part Number TLV62569DBVT
U102: MCP6001T-E/OT; SOT-23-5; Manufacturer Part Number MCP6001T-E/OT

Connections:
+3.3VA: C103.1, C108.1, R104.2, U100.3 (VOUT), U102.5 (V+); also elsewhere on the board
+3V3: C105.1, C106.1, D100.2 (A), L101.2, R101.2; also elsewhere on the board
+5V: C101.1, C104.1, L100.2, R100.2, U101.1 (EN), U101.4 (VIN); also elsewhere on the board
/Power/+5V_FILT: C102.1, R100.1, U100.2 (VIN)
/Power/BUCK_FB: C106.2, R101.1, R102.2, U101.5 (FB)
/Power/BUCK_SW: L101.1, U101.3 (SW)
/Power/LED_PWR_K: D100.1 (K), R103.2
/Power/VCOM: U102.1, U102.4 (-)
/Power/VREF: C107.1, R104.1, R105.2, U102.3 (+)
GND: C100.2, C101.2, C102.2, C103.2, C104.2, C105.2, C107.2, C108.2, R102.1, R103.1, R105.1, U100.1 (GND), U101.2 (GND), U102.2 (V-); also elsewhere on the board
VBUS: C100.1, L100.1; also elsewhere on the board

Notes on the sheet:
DCR=0R15
C(in/out)>10uF
V(out)=0.6*(1+100k/22k)=3.327V
I(DC)=500mA
Bias Generator
LP filter: fc=15Hz
100mA max.
f(sw)=1.5MHz
VBUS power comes from USB Type C connector (schematic page 2)
P(R)>1/8W
I(load)=0.25A max
Input Filtering & Analogue and Digital Supplies
[1] Power
WEBENCH Tools

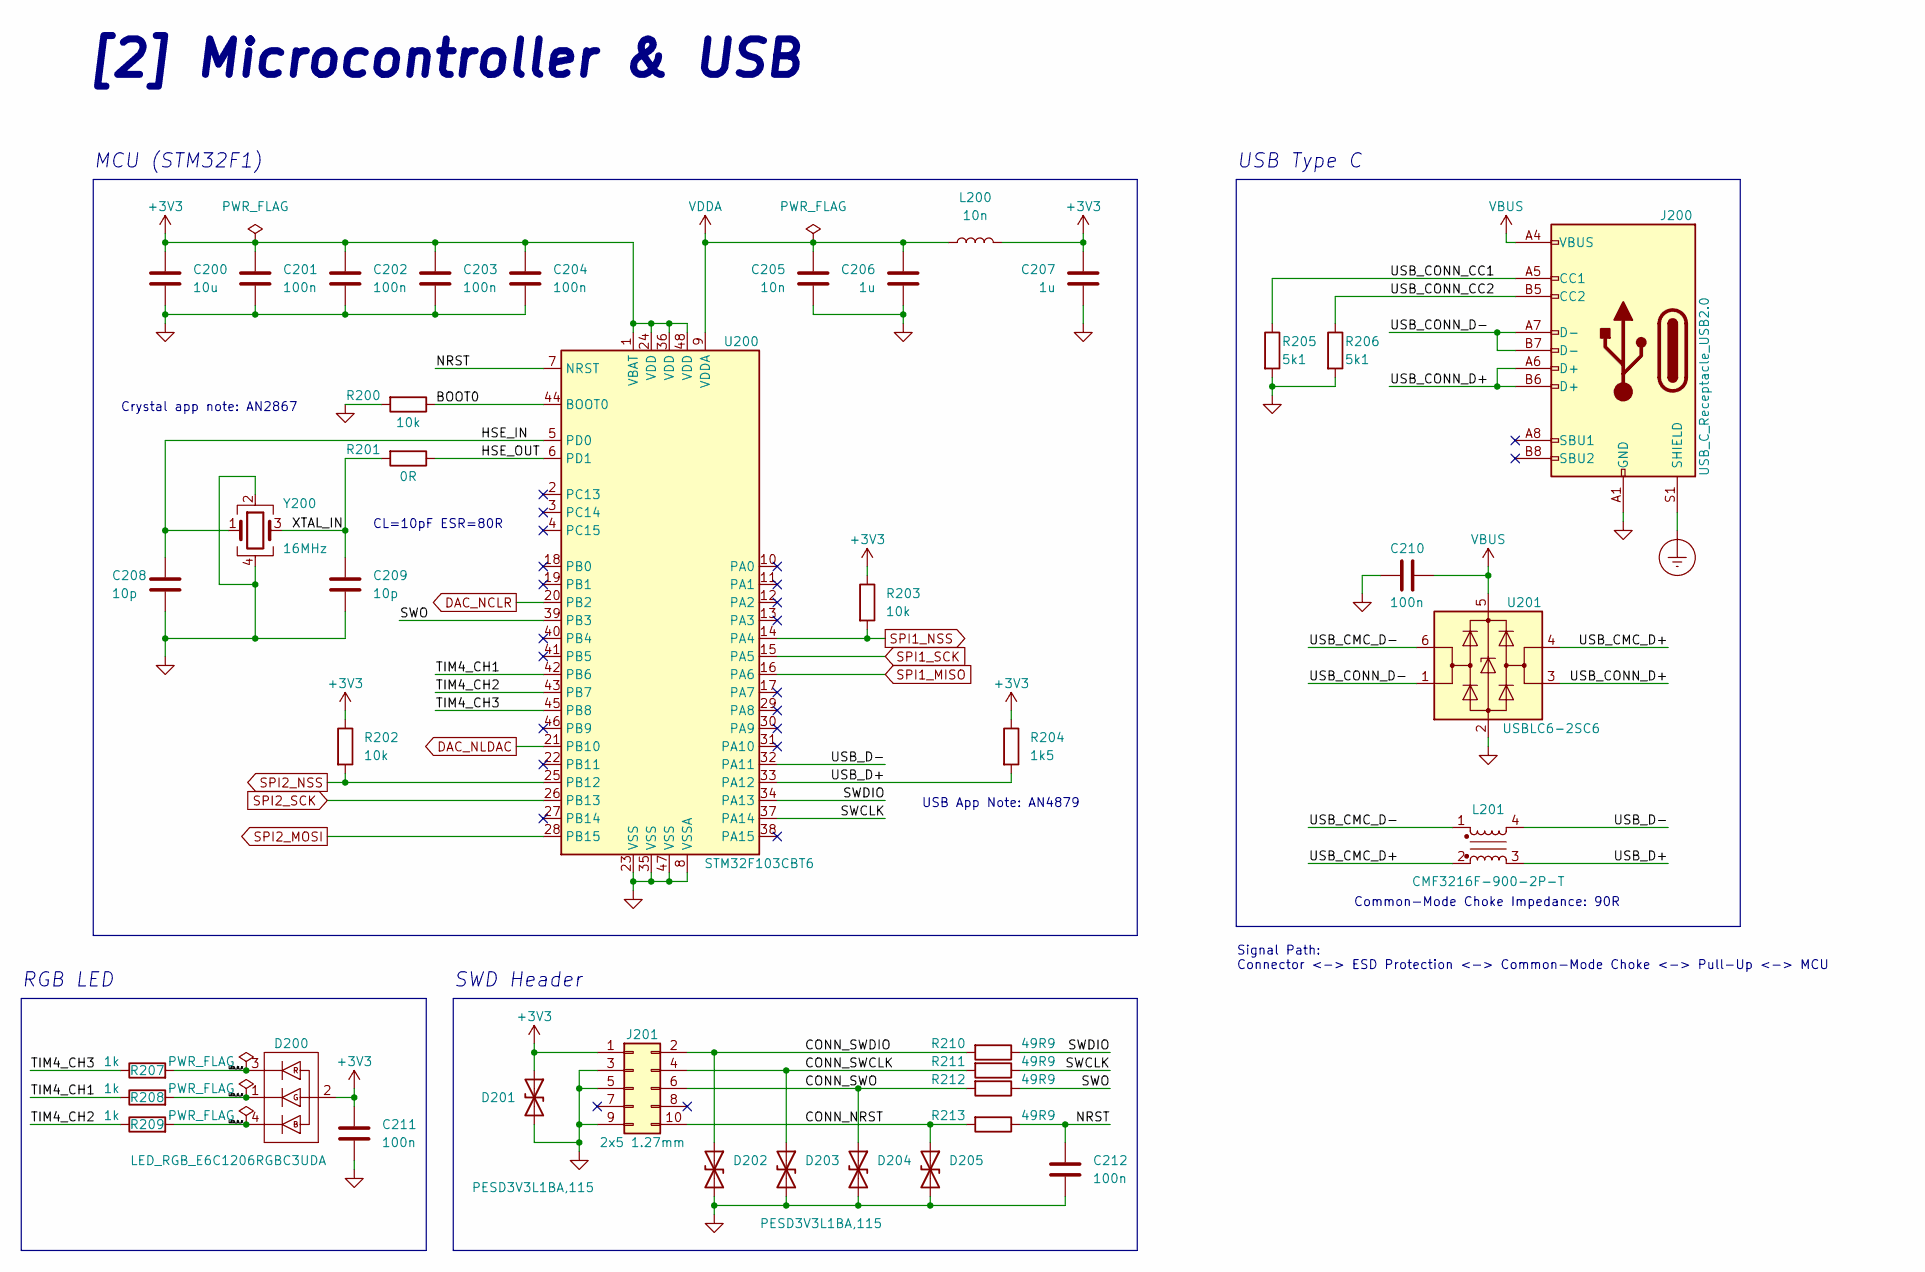
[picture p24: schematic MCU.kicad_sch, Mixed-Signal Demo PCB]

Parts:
C200: 10u; C_0603_1608Metric; Manufacturer Part Number CL10A106KQ8NNNL
C201, C202, C203, C204, C210, C211, C212: 100n; C_0402_1005Metric; Manufacturer Part Number C0402C104K8RACAUTO
C205: 10n; C_0402_1005Metric; Manufacturer Part Number C0402C103K4RACAUTO
C206, C207: 1u; C_0603_1608Metric; Manufacturer Part Number C0603C105K8RACAUTO7411
C208, C209: 10p; C_0402_1005Metric; Manufacturer Part Number GRT1555C1H100FA02D
D200: LED_RGB_E6C1206RGBC3UDA; LED_Cree-PLCC4_2x2mm_CW; Manufacturer Part Number E6C1206RGBC3UDA
D201, D202, D203, D204, D205: PESD3V3L1BA,115; D_SOD-323; Manufacturer Part Number PESD3V3L1BA,115
J200: USB_C_Receptacle_USB2.0; USB_C_Receptacle_HRO_TYPE-C-31-M-12; Manufacturer Part Number TYPE-C-31-M-12
J201: 2x5 1.27mm; PinHeader_2x05_P1.27mm_Vertical_SMD; Manufacturer Part Number M50-3600542R
L200: 10n; L_0402_1005Metric; Manufacturer Part Number AISC-0402HP-10NJ-T
L201: CMF3216F-900-2P-T; CMC-1206; Manufacturer Part Number CMF3216F-900-2P-T
R200, R202, R203: 10k; R_0402_1005Metric; Manufacturer Part Number ERJ-PA2J103X
R201: 0R; R_0402_1005Metric; Manufacturer Part Number CR0402AJ/-000GAS
R204: 1k5; R_0402_1005Metric; Manufacturer Part Number ERJ-PA2J152X
R205, R206: 5k1; R_0402_1005Metric; Manufacturer Part Number CR0402-JW-512GLF
R207, R208, R209: 1k; R_0402_1005Metric; Manufacturer Part Number CR0402-JW-102GLF
R210, R211, R212, R213: 49R9; R_0402_1005Metric; Manufacturer Part Number ERJ2RKD49R9X
U200: STM32F103CBT6; LQFP-48_7x7mm_P0.5mm; Manufacturer Part Number STM32F103CBT6
U201: USBLC6-2SC6; SOT-23-6; Manufacturer Part Number USBLC6-2SC6
Y200: 16MHz; Crystal_SMD_3225-4Pin_3.2x2.5mm; Manufacturer Part Number ECS-TXO-3225MV-160-TR

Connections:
+3V3: C200.1, C201.1, C202.1, C203.1, C204.1, C207.1, C211.1, D200.2, D201.1 (A1), J201.1, L200.2, R202.1, R203.1, R204.1, U200.1 (VBAT), U200.24 (VDD), U200.36 (VDD), U200.48 (VDD); also elsewhere on the board
/MCU/BOOT0: R200.1, U200.44 (BOOT0)
/MCU/CONN_NRST: D205.1 (A1), J201.10, R213.2
/MCU/CONN_SWCLK: D203.1 (A1), J201.4, R211.2
/MCU/CONN_SWDIO: D202.1 (A1), J201.2, R210.2
/MCU/CONN_SWO: D204.1 (A1), J201.6, R212.2
/MCU/HSE_IN: C208.1, U200.5 (PD0), Y200.1
/MCU/HSE_OUT: R201.1, U200.6 (PD1)
/MCU/LED_B_K: D200.4, R209.2
/MCU/LED_G_K: D200.1, R208.2
/MCU/LED_R_K: D200.3, R207.2
/MCU/NRST: C212.1, R213.1, U200.7 (NRST)
/MCU/SWCLK: R211.1, U200.37 (PA14)
/MCU/SWDIO: R210.1, U200.34 (PA13)
/MCU/SWO: R212.1, U200.39 (PB3)
/MCU/TIM4_CH1: R208.1, U200.42 (PB6)
/MCU/TIM4_CH2: R209.1, U200.43 (PB7)
/MCU/TIM4_CH3: R207.1, U200.45 (PB8)
/MCU/USB_CMC_D+: L201.2, U201.4 (I/O2)
/MCU/USB_CMC_D-: L201.1, U201.6 (I/O1)
/MCU/USB_CONN_CC1: J200.A5 (CC1), R205.1
/MCU/USB_CONN_CC2: J200.B5 (CC2), R206.1
/MCU/USB_CONN_D+: J200.A6 (D+), J200.B6 (D+), U201.3 (I/O2)
/MCU/USB_CONN_D-: J200.A7 (D-), J200.B7 (D-), U201.1 (I/O1)
/MCU/USB_D+: L201.3, R204.2, U200.33 (PA12)
/MCU/USB_D-: L201.4, U200.32 (PA11)
/MCU/XTAL_IN: C209.1, R201.2, Y200.3
DAC_NCLR: U200.20 (PB2); also elsewhere on the board
DAC_NLDAC: U200.21 (PB10); also elsewhere on the board
Earth_Protective: J200.S1 (SHIELD); also elsewhere on the board
GND: C200.2, C201.2, C202.2, C203.2, C204.2, C205.2, C206.2, C207.2, C208.2, C209.2, C210.2, C211.2, C212.2, D201.2 (A2), D202.2 (A2), D203.2 (A2), D204.2 (A2), D205.2 (A2), J200.A1 (GND), J200.A12 (GND), J200.B1 (GND), J200.B12 (GND), J201.3, J201.5, J201.9, R200.2, R205.2, R206.2, U200.8 (VSSA), U200.23 (VSS), U200.35 (VSS), U200.47 (VSS), U201.2 (GND), Y200.2, Y200.4; also elsewhere on the board
SPI1_MISO: U200.16 (PA6); also elsewhere on the board
SPI1_NSS: R203.2, U200.14 (PA4); also elsewhere on the board
SPI1_SCK: U200.15 (PA5); also elsewhere on the board
SPI2_MOSI: U200.28 (PB15); also elsewhere on the board
SPI2_NSS: R202.2, U200.25 (PB12); also elsewhere on the board
SPI2_SCK: U200.26 (PB13); also elsewhere on the board
VBUS: C210.1, J200.A4 (VBUS), J200.A9 (VBUS), J200.B4 (VBUS), J200.B9 (VBUS), U201.5 (VBUS); also elsewhere on the board
VDDA: C205.1, C206.1, L200.1, U200.9 (VDDA)

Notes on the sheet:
Signal Path: Connector <-> ESD Protection <-> Common-Mode Choke <-> Pull-Up <-> MCU
RGB LED
Crystal app note: AN2867
SWD Header
USB App Note: AN4879
Common-Mode Choke Impedance: 90R
[2] Microcontroller & USB
CL=10pF ESR=80R
MCU (STM32F1)
USB Type C

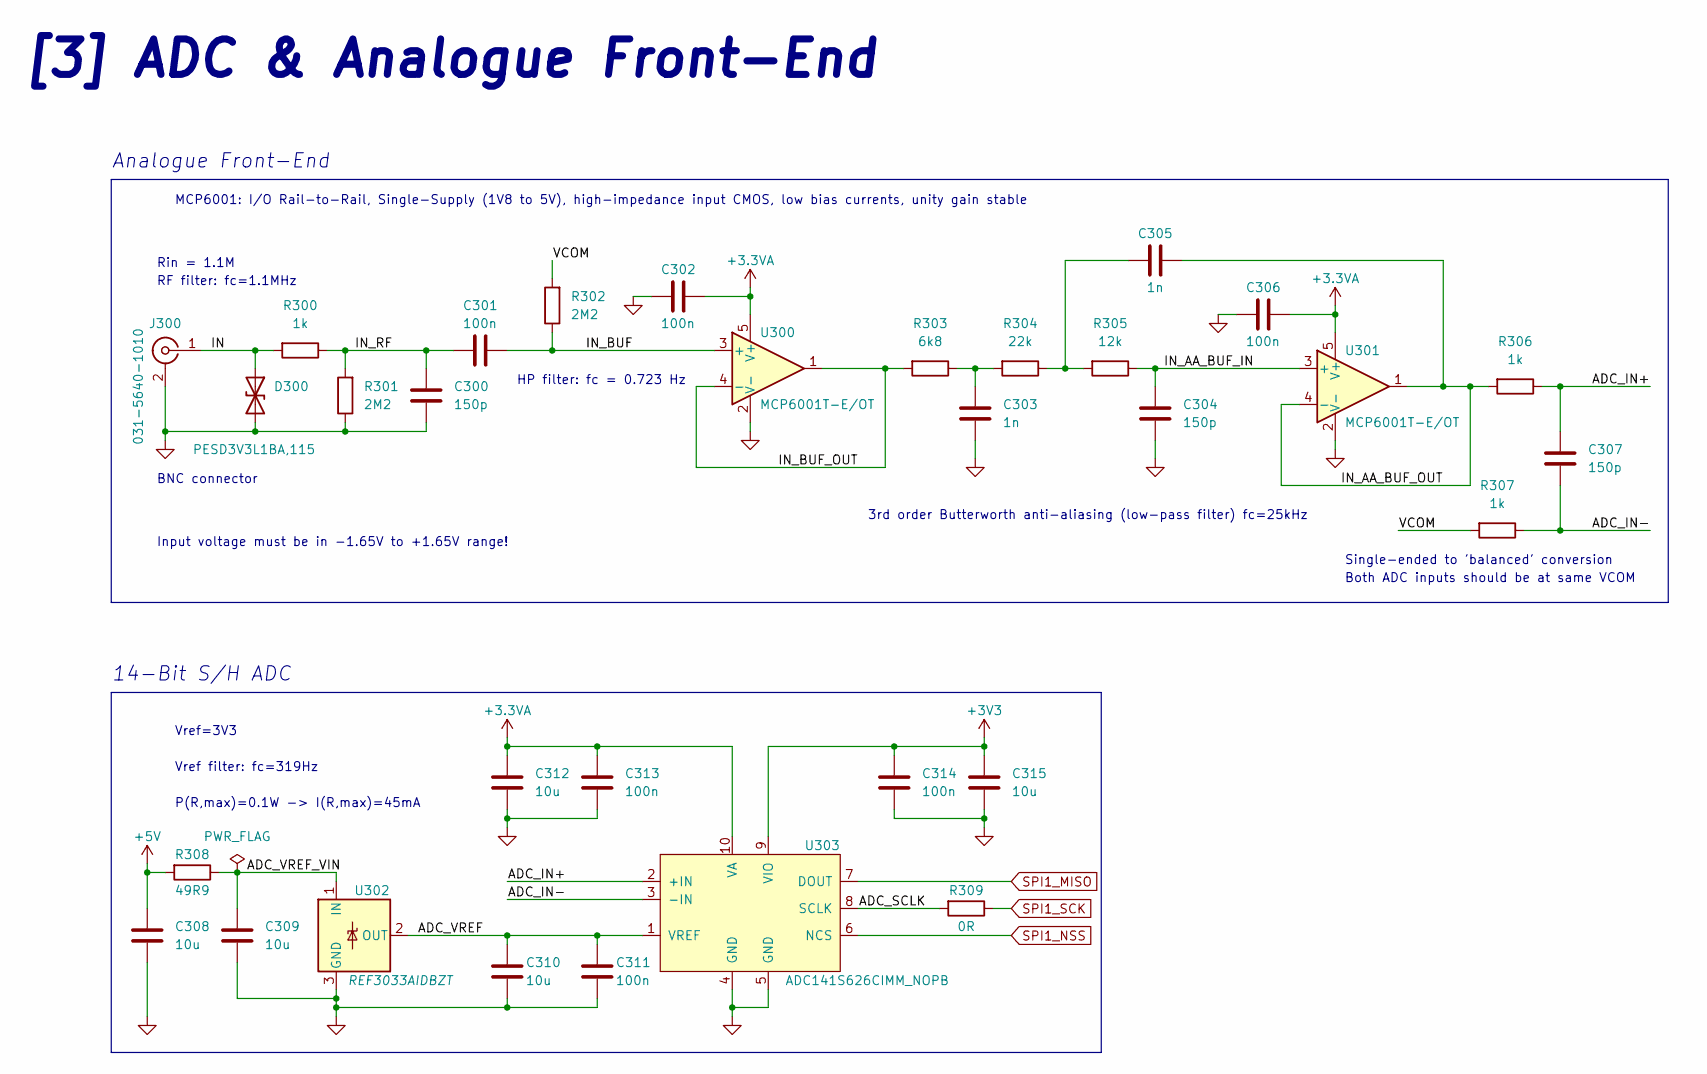
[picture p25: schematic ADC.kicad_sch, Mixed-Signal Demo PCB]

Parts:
C300, C304, C307: 150p; C_0402_1005Metric; Manufacturer Part Number 0402N151F100CT
C301, C302, C306, C311, C313, C314: 100n; C_0402_1005Metric; Manufacturer Part Number C0402C104K8RACAUTO
C303, C305: 1n; C_0402_1005Metric; Manufacturer Part Number AC0402JRNPO9BN102
C308, C309, C310, C312, C315: 10u; C_0603_1608Metric; Manufacturer Part Number CL10A106KQ8NNNL
D300: PESD3V3L1BA,115; D_SOD-323; Manufacturer Part Number PESD3V3L1BA,115
J300: 031-5640-1010; AMPHENOL-BNC-031-5640-1010; Manufacturer Part Number 031-5640
R300, R306, R307: 1k; R_0402_1005Metric; Manufacturer Part Number CR0402-JW-102GLF
R301, R302: 2M2; R_0402_1005Metric; Manufacturer Part Number ERJ-U02J205X
R303: 6k8; R_0402_1005Metric; Manufacturer Part Number ERJ-2GEJ682X
R304: 22k; R_0402_1005Metric; Manufacturer Part Number CR0402-JW-223GLF
R305: 12k; R_0402_1005Metric; Manufacturer Part Number CR0402-JW-123GLF
R308: 49R9; R_0402_1005Metric; Manufacturer Part Number ERJ2RKD49R9X
R309: 0R; R_0402_1005Metric; Manufacturer Part Number CR0402AJ/-000GAS
U300, U301: MCP6001T-E/OT; SOT-23-5; Manufacturer Part Number MCP6001T-E/OT
U302: REF3033AIDBZT; SOT-23; Manufacturer Part Number REF3033AIDBZT
U303: ADC141S626CIMM_NOPB; VSSOP-10; Manufacturer Part Number ADC141S626CIMM/NOPB

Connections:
+3.3VA: C302.1, C306.1, C312.1, C313.1, U300.5 (V+), U301.5 (V+), U303.10 (VA); also elsewhere on the board
+3V3: C314.1, C315.1, U303.9 (VIO); also elsewhere on the board
+5V: C308.1, R308.2; also elsewhere on the board
/ADC/ADC_IN+: C307.1, R306.1, U303.2 (+IN)
/ADC/ADC_IN-: C307.2, R307.1, U303.3 (-IN)
/ADC/ADC_SCLK: R309.2, U303.8 (SCLK)
/ADC/ADC_VREF: C310.1, C311.1, U302.2 (OUT), U303.1 (VREF)
/ADC/ADC_VREF_VIN: C309.1, R308.1, U302.1 (IN)
/ADC/IN: D300.1 (A1), J300.1 (In), R300.2
/ADC/IN_AA_BUF_IN: C304.1, R305.1, U301.3 (+)
/ADC/IN_AA_BUF_OUT: C305.2, R306.2, U301.1, U301.4 (-)
/ADC/IN_BUF: C301.1, R302.1, U300.3 (+)
/ADC/IN_BUF_OUT: R303.2, U300.1, U300.4 (-)
/ADC/IN_RF: C300.1, C301.2, R300.1, R301.2
/ADC/VCOM: R302.2, R307.2
GND: C300.2, C302.2, C303.2, C304.2, C306.2, C308.2, C309.2, C310.2, C311.2, C312.2, C313.2, C314.2, C315.2, D300.2 (A2), J300.2 (Ext), R301.1, U300.2 (V-), U301.2 (V-), U302.3 (GND), U303.4 (GND), U303.5 (GND); also elsewhere on the board
unnamed: C303.1, R303.1, R304.2
unnamed: C305.1, R304.1, R305.2
SPI1_MISO: U303.7 (DOUT); also elsewhere on the board
SPI1_NSS: U303.6 (NCS); also elsewhere on the board
SPI1_SCK: R309.1; also elsewhere on the board

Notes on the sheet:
HP filter: fc = 0.723 Hz
Both ADC inputs should be at same VCOM
BNC connector
Rin = 1.1M
14-Bit S/H ADC
Vref filter: fc=319Hz
Input voltage must be in -1.65V to +1.65V range!
Analogue Front-End
Single-ended to 'balanced' conversion
RF filter: fc=1.1MHz
3rd order Butterworth anti-aliasing (low-pass filter) fc=25kHz
MCP6001: I/O Rail-to-Rail, Single-Supply (1V8 to 5V), high-impedance input CMOS, low bias currents, unity gain stable
P(R,max)=0.1W -> I(R,max)=45mA
Vref=3V3
[3] ADC & Analogue Front-End

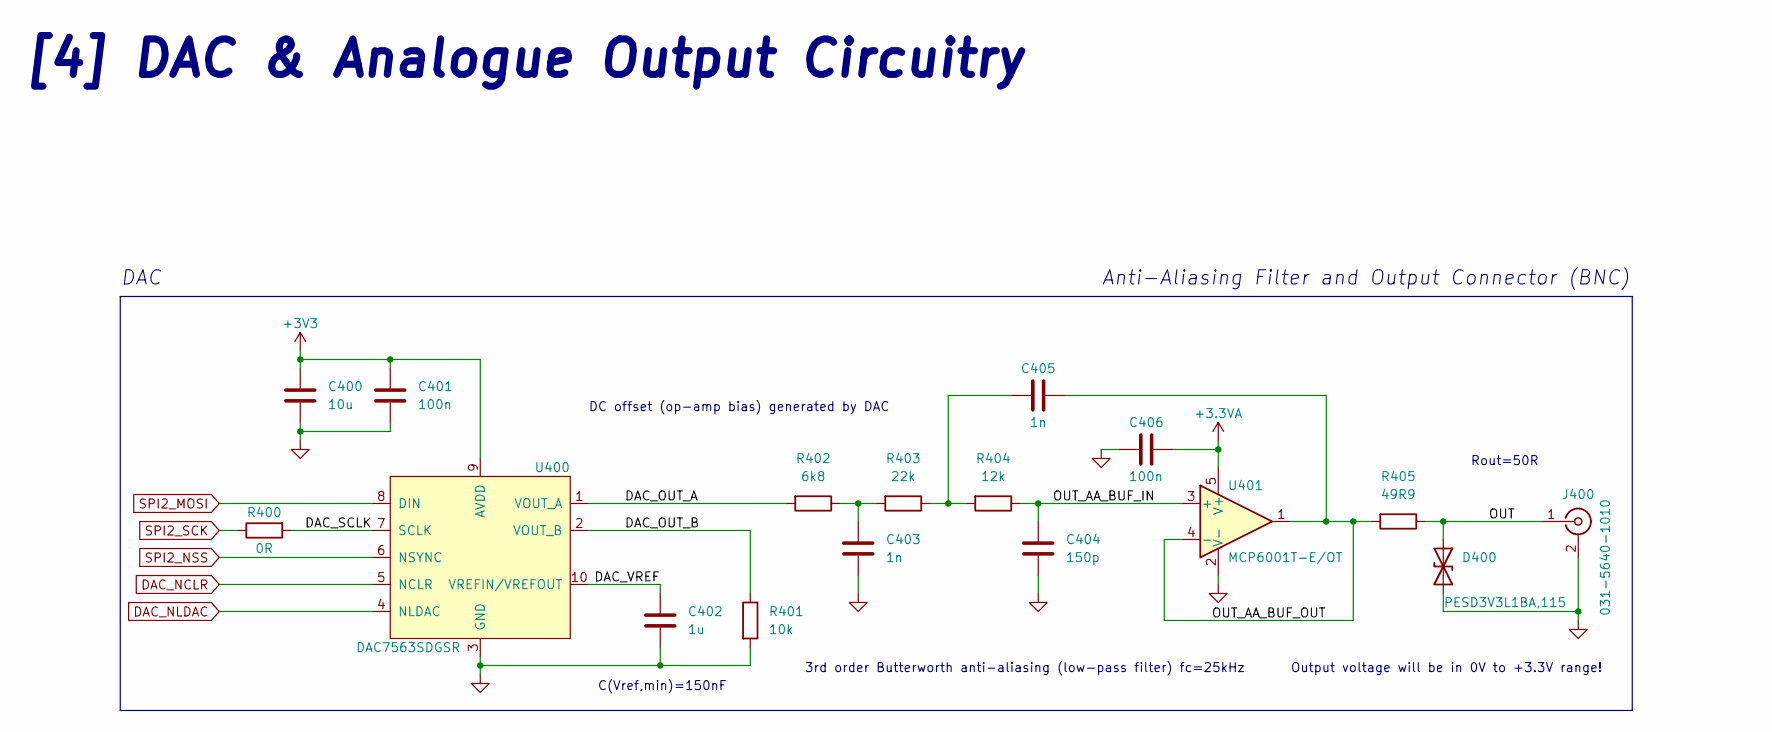
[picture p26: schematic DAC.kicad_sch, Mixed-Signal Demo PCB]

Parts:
C400: 10u; C_0603_1608Metric; Manufacturer Part Number CL10A106KQ8NNNL
C401, C406: 100n; C_0402_1005Metric; Manufacturer Part Number C0402C104K8RACAUTO
C402: 1u; C_0603_1608Metric; Manufacturer Part Number C0603C105K8RACAUTO7411
C403, C405: 1n; C_0402_1005Metric; Manufacturer Part Number AC0402JRNPO9BN102
C404: 150p; C_0402_1005Metric; Manufacturer Part Number 0402N151F100CT
D400: PESD3V3L1BA,115; D_SOD-323; Manufacturer Part Number PESD3V3L1BA,115
J400: 031-5640-1010; AMPHENOL-BNC-031-5640-1010; Manufacturer Part Number 031-5640
R400: 0R; R_0402_1005Metric; Manufacturer Part Number CR0402AJ/-000GAS
R401: 10k; R_0402_1005Metric; Manufacturer Part Number ERJ-PA2J103X
R402: 6k8; R_0402_1005Metric; Manufacturer Part Number ERJ-2GEJ682X
R403: 22k; R_0402_1005Metric; Manufacturer Part Number CR0402-JW-223GLF
R404: 12k; R_0402_1005Metric; Manufacturer Part Number CR0402-JW-123GLF
R405: 49R9; R_0402_1005Metric; Manufacturer Part Number ERJ2RKD49R9X
U400: DAC7563SDGSR; VSSOP-10; Manufacturer Part Number DAC7563SDGSR
U401: MCP6001T-E/OT; SOT-23-5; Manufacturer Part Number MCP6001T-E/OT

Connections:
+3.3VA: C406.1, U401.5 (V+); also elsewhere on the board
+3V3: C400.1, C401.1, U400.9 (AVDD); also elsewhere on the board
/DAC/DAC_OUT_A: R402.2, U400.1 (VOUT_A)
/DAC/DAC_OUT_B: R401.1, U400.2 (VOUT_B)
/DAC/DAC_SCLK: R400.2, U400.7 (SCLK)
/DAC/DAC_VREF: C402.1, U400.10 (VREFIN/VREFOUT)
/DAC/OUT: D400.1 (A1), J400.1 (In), R405.1
/DAC/OUT_AA_BUF_IN: C404.1, R404.1, U401.3 (+)
/DAC/OUT_AA_BUF_OUT: C405.2, R405.2, U401.1, U401.4 (-)
DAC_NCLR: U400.5 (NCLR); also elsewhere on the board
DAC_NLDAC: U400.4 (NLDAC); also elsewhere on the board
GND: C400.2, C401.2, C402.2, C403.2, C404.2, C406.2, D400.2 (A2), J400.2 (Ext), R401.2, U400.3 (GND), U401.2 (V-); also elsewhere on the board
unnamed: C403.1, R402.1, R403.2
unnamed: C405.1, R403.1, R404.2
SPI2_MOSI: U400.8 (DIN); also elsewhere on the board
SPI2_NSS: U400.6 (NSYNC); also elsewhere on the board
SPI2_SCK: R400.1; also elsewhere on the board

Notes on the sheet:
[4] DAC & Analogue Output Circuitry
Anti-Aliasing Filter and Output Connector (BNC)
Rout=50R
Output voltage will be in 0V to +3.3V range!
DAC
C(Vref,min)=150nF
3rd order Butterworth anti-aliasing (low-pass filter) fc=25kHz
DC offset (op-amp bias) generated by DAC

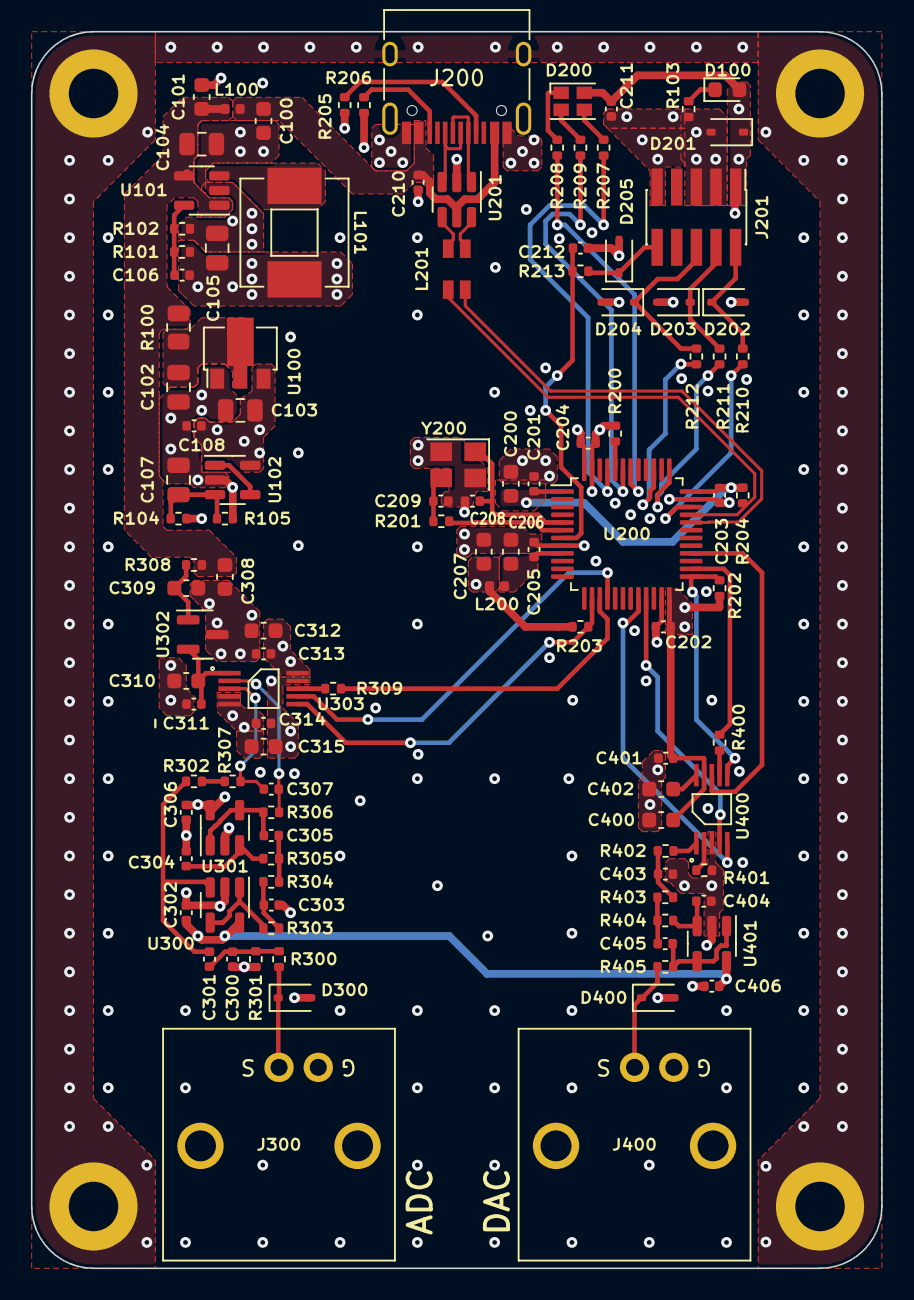
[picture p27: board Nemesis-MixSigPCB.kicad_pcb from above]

Board: 4 copper layers, 55.0 x 80.0 mm, 114 parts (0 on the bottom side), 70 nets.
